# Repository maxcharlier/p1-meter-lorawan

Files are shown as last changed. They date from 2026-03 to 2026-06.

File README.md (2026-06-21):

# Belgian Smart Meter P1 → LoRaWAN

Read your Belgian smart meter (ORES / Fluvius) via the **P1 port** and forward aggregated electrical data over **LoRaWAN** every 15 minutes using a Heltec CubeCell board.

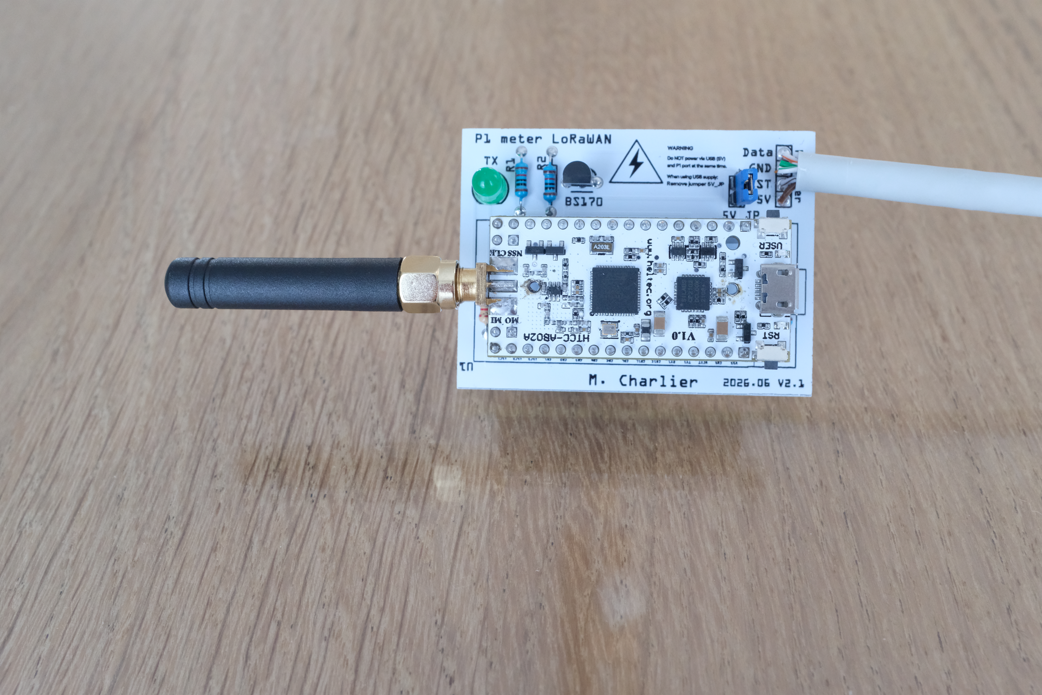
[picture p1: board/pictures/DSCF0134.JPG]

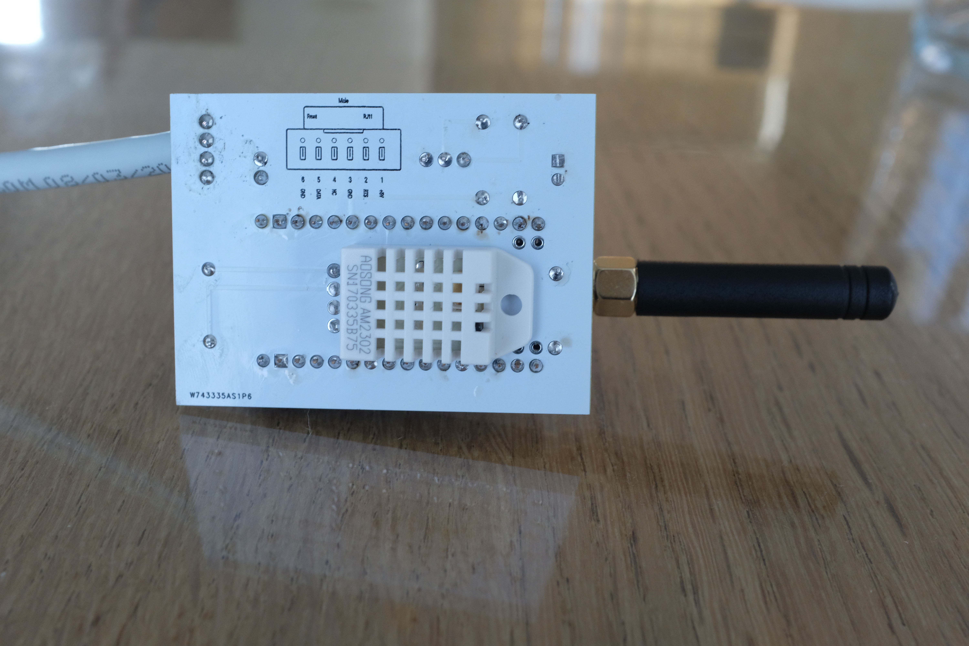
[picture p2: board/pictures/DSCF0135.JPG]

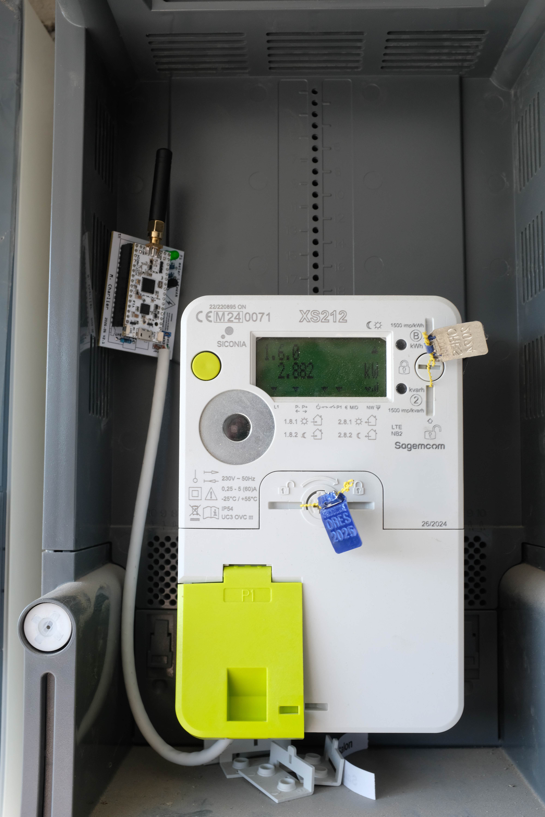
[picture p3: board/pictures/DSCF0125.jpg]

## Quick start

```bash
# 1. Clone the repository
git clone https://github.com/YOUR_USERNAME/p1-meter-lorawan.git
cd p1-meter-lorawan

# 2. Enable the pre-commit hook (blocks accidental credential leaks)
git config core.hooksPath .githooks

# 3. Generate your LoRaWAN credentials from your TTN / Chirpstack device page
python3 credentials.py --deveui AA:BB:CC:DD:EE:FF:00:11 \\
                        --appeui 00:00:00:00:00:00:00:00 \\
                        --appkey AA:BB:CC:DD:EE:FF:00:11:22:33:44:55:66:77:88:99 \\
                        --write-h mono-phase-lorawan/credentials.h

# 4. Install required Arduino libraries (Tools → Manage Libraries):
#    - "DHT sensor library" by Adafruit  (also install its dependency: Adafruit Unified Sensor)

# 5. Open the sketch in Arduino IDE, build and flash
```

> **Credentials:** `credentials.h` is git-ignored. A zeroed template is provided as
> `credentials.h.example` in each sketch folder. The pre-commit hook will block any
> commit that contains non-zero keys in `credentials.h`.

---

## Project steps

| Folder | Purpose |
|---|---|
| [`serial-config-checker/`](serial-config-checker/) | Dump raw P1 serial output to USB — verify wiring and baud rate |
| [`mono-phase-lorawan/`](mono-phase-lorawan/) | Parse OBIS fields, aggregate statistics, transmit over LoRaWAN (single-phase meter) |
| [`three-phase-lorawan/`](three-phase-lorawan/) | Same as above but with L2/L3 voltage and current stats (three-phase meter) |
| [`mono-phase-overvoltage/`](mono-phase-overvoltage/) | mono-phase-lorawan + Synergrid C10/11 over-voltage detection (253 V / 264.5 V) |

Before flashing any sketch, see **[board-setup.md](board-setup.md)** for driver installation, Arduino IDE board support, and upload instructions.

---

## Hardware

### Why the Heltec CubeCell HTCC-AB02A?

The CubeCell HTCC-AB02A was chosen because it exposes **two independent hardware serial (UART) lines**:

- **Serial** (UART0) — connected to the USB bridge, used for debug output and programming.
- **Serial1** (UART1, pins UART_RX2 / UART_TX2) — dedicated to reading the P1 port of the electrical meter.

Having two separate hardware UARTs is essential: the P1 port streams data continuously at 115200 baud 8N1, so it must be handled on a real hardware peripheral — a software serial implementation would lose bytes at that speed or block the LoRaWAN stack.

As an added bonus, the board integrates a **Semtech SX1262 LoRa transceiver and a 868 MHz antenna**, and is supported by the Heltec Arduino SDK with a ready-made LoRaWAN stack.

Board documentation and pinout are available in [`sources/`](sources/).

### Components

| Component | Reference | Notes |
|---|---|---|
| Arduino board | Heltec CubeCell HTCC-AB02A | Two hardware UARTs + integrated LoRa 868 MHz |
| Signal inverter / level shifter | BS170 N-channel MOSFET | Inverts 5 V → 3.3 V (common-drain) |
| Meter connector | RJ11 6P6C | P1 port on Belgian smart meters (pins 1, 2, 3, 5, 6 used) |
| Environmental sensor | DHT22 | Temperature + humidity (all sketches except serial-config-checker) |
| Pull-up resistors | 3 × 10 kΩ (R1, R2) | BS170 inverter biasing (R1 on source/RX2, R2 on gate/Data) |
| DHT pull-up resistor | 1 × 10 kΩ (RPullUpDHT) | DHT22 data line pull-up to VEXT |
| LED current limiter | 1 × 220 Ω (R3) | TX indicator LED |
| TX indicator LED | 5 mm red LED | Driven by GPIO1 via R3 |
| Power jumper | 2-pin header (5V_JP) | Connects P1 +5 V to VIN — **remove when using USB** |
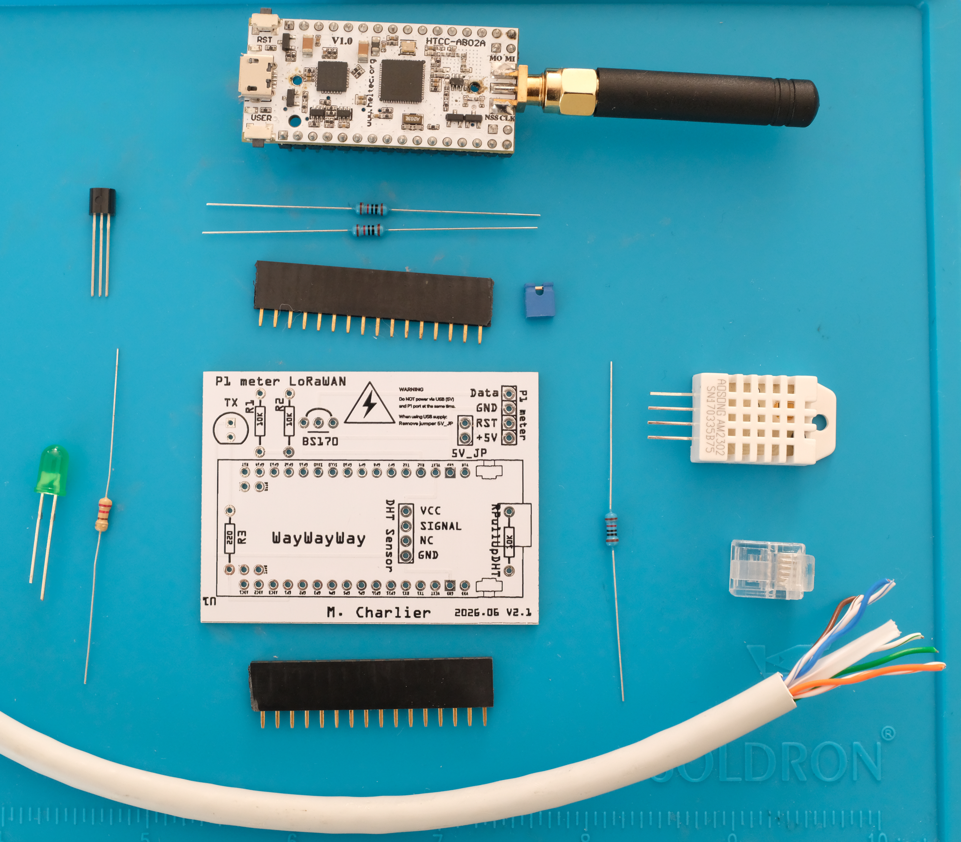
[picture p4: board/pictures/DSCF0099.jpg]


For the PCB, you can print it with gerber files from `board/p1-meter-lorawan-v2.1`. The PCB was created using [Fritzing](https://fritzing.org/) and can be modified in `board/p1-meter-lorawan-v2.1.fzz`
### Wiring — P1 port to CubeCell

> **WARNING — do not connect both power sources at the same time.**
> The CubeCell is powered from the meter's 5 V line (VIN pin).
> If you also plug in a USB cable while the meter is connected, you will feed two power sources into the board simultaneously, which can damage the board or the meter.
> Remove the 5V_JP jumper before connecting USB (for programming or debug).

The P1 port outputs **inverted** 5 V TTL serial (5 V = logic 0, 0 V = logic 1).
The BS170 MOSFET inverts the signal and shifts it to 3.3 V in a single stage using a common-drain configuration:
- **Gate** receives the P1 data signal (with R2 10 kΩ pull-up to GPIO7).
- **Source** outputs the inverted 3.3 V signal to UART_RX2 (with R1 10 kΩ pull-up to GPIO7).
- **Drain** is tied to GND.

GPIO7 is set HIGH to provide 3.3 V through R1 and R2, biasing the inverter. Setting GPIO7 LOW disables reception.

```
Belgian Meter P1 (RJ11 6P6C)     CubeCell HTCC-AB02A
─────────────────────────────────────────────────────
Pin 1  +5V  ─────[5V_JP]────────→  VIN  (powers the board)
Pin 2  RTS  ─────────────────────→  +5V  (Data Request, active HIGH — hardwired to 5 V)
Pin 3  GND  ─────────────────────→  GND
Pin 4  NC
Pin 5  Data ─────────────────────→  BS170 gate (via R2 10 kΩ pull-up to GPIO7)
Pin 6  GND  ─────────────────────→  GND

BS170 inverter (common-drain configuration):
       BS170 gate   ← P1 Data + R2 (10 kΩ pull-up to GPIO7)
       BS170 source → UART_RX2 (Serial1) + R1 (10 kΩ pull-up to GPIO7)
       BS170 drain  → GND

GPIO7 (OUTPUT, set HIGH) provides 3.3 V pull-up bias through R1 and R2,
effectively enabling/disabling the inverter.
```

> **Data Request line**: The P1 spec requires the Data Request line (RJ11 pin 2) to be
> pulled HIGH to enable telegram output. On this PCB, it is hardwired to the +5 V rail,
> so the meter streams continuously whenever power is present.

### DHT22 (mono-phase-lorawan, three-phase-lorawan, mono-phase-overvoltage)

```
DHT22               CubeCell
─────────────────────────────
VCC  ─────────────→  VEXT (switchable 3.3 V)
GND  ─────────────→  GND
DATA ─[10 kΩ]─────→  GPIO9 / SDA1  (pull-up to VEXT)
```

### GPIO pin summary

| GPIO | Direction | Function |
|---|---|---|
| GPIO7  | OUTPUT | BS170 inverter enable (set HIGH to provide 3.3 V pull-up bias via R1 + R2) |
| GPIO9 / SDA1 | INPUT | DHT22 data (10 kΩ pull-up to VEXT) |
| GPIO5  | INPUT  | Floating — used for `randomSeed()` |
| GPIO1  | OUTPUT | TX LED indicator (via R3 220 Ω) |
| USER_KEY | INPUT_PULLDOWN | User button (manual LoRa send) |
| UART_RX2 / UART_TX2 | — | Hardware Serial1, 115200 8N1 (RX2 receives inverted P1 data via BS170) |

---

## P1 port & DSMR/ESMR protocol

Belgian smart meters (Fluvius in Flanders, ORES in Wallonia) expose a **P1 port** that outputs an DSMR 5.0 / ESMR 5.0 telegram every second.

### Telegram structure

```
/FLU5\253770234_A              ← header: slash + manufacturer ID

0-0:1.0.0(240904223307S)       ← OBIS object: timestamp
1-0:1.8.1(000328.928*kWh)      ← OBIS object: consumption T1
...
!E4C7                          ← CRC-16 checksum
```

Each telegram line contains one **OBIS code** followed by its value in parentheses.

### OBIS code format

```
A-B:C.D.E
│ │ │ │ └─ Tariff / sub-index
│ │ │ └─── Quantity (measurement type)
│ │ └───── Value group (channel)
│ └──────── Medium group (0=abstract, 1=electricity, 2=heat, 3=gas, 6=water)
└────────── Energy type
```

### OBIS codes extracted by this project

All sketches (except serial-config-checker) extract these fields:

| OBIS code | Name | Unit | Description |
|---|---|---|---|
| `0-0:1.0.0` | Timestamp | — | Date-time stamp (local time, S=Summer/CEST, W=Winter/CET) |
| `1-0:1.8.1` | Cons-Day-Wh | Wh | Total electricity delivered to client — Tariff 1 (day) |
| `1-0:1.8.2` | Cons-Night-Wh | Wh | Total electricity delivered to client — Tariff 2 (night) |
| `1-0:2.8.1` | Prod-Day-Wh | Wh | Total electricity delivered by client — Tariff 1 (day) |
| `1-0:2.8.2` | Prod-Night-Wh | Wh | Total electricity delivered by client — Tariff 2 (night) |
| `0-0:96.14.0` | Night1-Day2 | — | Active tariff indicator (1=night/T1, 2=day/T2) |
| `1-0:1.7.0` | Cons-W | W | Instantaneous active power import (+P total) |
| `1-0:2.7.0` | Prod-W | W | Instantaneous active power export (-P total) |
| `1-0:32.7.0`  | Inst-L1-dV | dV | Instantaneous voltage L1 (decivolts, divide by 10 for V) |
| `1-0:31.7.0`  | Inst-L1-cA | cA | Instantaneous current L1 (centiamps, divide by 100 for A) |

three-phase-lorawan additionally extracts:

| OBIS code | Name | Unit | Description |
|---|---|---|---|
| `1-0:52.7.0` | Inst-L2-dV | dV | Instantaneous voltage L2 (decivolts) |
| `1-0:72.7.0` | Inst-L3-dV | dV | Instantaneous voltage L3 (decivolts) |
| `1-0:51.7.0` | Inst-L2-cA | cA | Instantaneous current L2 (centiamps) |
| `1-0:71.7.0` | Inst-L3-cA | cA | Instantaneous current L3 (centiamps) |

**Sources:**
- DSMR P1 Companion Standard v5.0.2 — [Netbeheer Nederland](https://www.netbeheernederland.nl/publicatie/dsmr-502-p1-companion-standard)
- Fluvius P1 port specification — [Digitale Meters in Vlaanderen](https://www.fluvius.be/nl/thema/meters-en-meterstanden/digitale-meter)
- ORES S1 port specification (Wallonia)
- IEC 62056-21 / OBIS object identification system

---

## Software architecture

### P1 parser

The telegram parser is adapted from [Maarten Pennings' eMeterP1port project (gen2)](https://github.com/maarten-pennings/eMeterP1port/tree/master/gen2).
It is a character-by-character state machine with CRC-16 validation.

States: `IDLE` → `HEAD` → `BODY` → `CSUM` → `IDLE`

CRC-16 polynomial: `x16 + x15 + x2 + 1` (0xA001 reflected).

### Statistics aggregation

Since LoRaWAN duty-cycle limits transmission to once every 15 minutes, ~900 samples are collected per period. For each measured quantity the code tracks:

- **Minimum** value in the window
- **Maximum** value (critical for voltage spike detection)
- **Mean** (sum / count)
- **Sample count** (data quality)

### LoRaWAN transmission timing

A random delay (15–60 s after a quarter-hour boundary) is added before transmitting to avoid all devices on a network transmitting simultaneously.

### Over-voltage detection (mono-phase-overvoltage only)

Belgian grid protection thresholds per **Synergrid C10/11** and **EN 50549-1** (230 V nominal):

| Stage | Threshold | Trip time | Threshold in decivolts |
|---|---|---|---|
| Stage 1 (U>) | 1.10 × 230 V = **253.0 V** | 1.5 s sustained | 2530 dV |
| Stage 2 (U>>) | 1.15 × 230 V = **264.5 V** | 0.2 s instant | 2645 dV |

When a grid-connected solar inverter detects sustained over-voltage it disconnects and waits ~60 s before reconnecting. This module tracks:

- Total samples above Stage 1 threshold
- Total samples above Stage 2 threshold
- Maximum consecutive samples above Stage 1 (if ≥ 2 consecutive at 1 sample/s → inverter likely tripped)

---

## LoRaWAN payload format (v2)

Each sketch uses the same frame version (v2) and a shared header, with fields added per sketch. The **NB Phases** nibble in byte 0 tells the decoder which format to expect.

### mono-phase-lorawan / mono-phase-overvoltage — 62 bytes (68 with over-voltage)

| Field | Bits | Byte index | Detail |
|---|---|---|---|
| Frame version | 4 | 0 | Value: 2 |
| User button | 1 | 0 | Pressed = 1 |
| NB Phases | 2 | 0 | Value: 1 |
| RESERVED | 1 | 0 | — |
| Timestamp | 32 | 1 | Unix timestamp (UTC) |
| Cons-Day-Wh | 32 | 5 | Cumulative Wh |
| Cons-Night-Wh | 32 | 9 | Cumulative Wh |
| Prod-Day-Wh | 32 | 13 | Cumulative Wh |
| Prod-Night-Wh | 32 | 17 | Cumulative Wh |
| Night1-Day2 | 8 | 21 | Current tariff |
| Nb Samples | 16 | 22 | Sample count in period |
| Cons-W stats | 72 | 24 | Min/Max/Mean (W) |
| Prod-W stats | 72 | 33 | Min/Max/Mean (W) |
| L1-dV stats | 72 | 42 | Min/Max/Mean (decivolts) |
| L1-cA stats | 72 | 51 | Min/Max/Mean (centiamps) |
| Temperature | 8 | 60 | DHT22: `(val / 2) - 40 = °C` |
| Humidity | 8 | 61 | DHT22: 0–100 % |
| L1-over-253V | 16 | 62 | Stage 1 count *(mono-phase-overvoltage only, if > 0)* |
| L1-over-264.5V | 16 | 64 | Stage 2 count *(mono-phase-overvoltage only, if Stage 1 > 0)* |
| L1-max-consec-253 | 16 | 66 | Max streak *(mono-phase-overvoltage only, if Stage 1 > 0)* |

> The 6 over-voltage bytes are only appended when `L1-over-253V > 0`, saving bandwidth in normal operation.

### three-phase-lorawan — 98 bytes

Same header and common fields as above (bytes 0–59), then:

| Field | Bits | Byte index | Detail |
|---|---|---|---|
| Frame version | 4 | 0 | Value: 2 |
| User button | 1 | 0 | Pressed = 1 |
| NB Phases | 2 | 0 | Value: 3 |
| RESERVED | 1 | 0 | — |
| Timestamp | 32 | 1 | Unix timestamp (UTC) |
| Cons-Day-Wh | 32 | 5 | Cumulative Wh |
| Cons-Night-Wh | 32 | 9 | Cumulative Wh |
| Prod-Day-Wh | 32 | 13 | Cumulative Wh |
| Prod-Night-Wh | 32 | 17 | Cumulative Wh |
| Night1-Day2 | 8 | 21 | Current tariff |
| Nb Samples | 16 | 22 | Sample count in period |
| Cons-W stats | 72 | 24 | Min/Max/Mean (W) |
| Prod-W stats | 72 | 33 | Min/Max/Mean (W) |
| L1-dV stats | 72 | 42 | Min/Max/Mean (decivolts) |
| L1-cA stats | 72 | 51 | Min/Max/Mean (centiamps) |
| L2-dV stats | 72 | 60 | Min/Max/Mean (decivolts) |
| L3-dV stats | 72 | 69 | Min/Max/Mean (decivolts) |
| L2-cA stats | 72 | 78 | Min/Max/Mean (centiamps) |
| L3-cA stats | 72 | 87 | Min/Max/Mean (centiamps) |
| Temperature | 8 | 96 | DHT22: `(val / 2) - 40 = °C` |
| Humidity | 8 | 97 | DHT22: 0–100 % |

> 98 bytes requires at least DR3 (SF9/125 kHz) in EU868. DR0–DR2 cannot carry this payload.

Each Min/Max/Mean stat block is 3 × 3 bytes (24-bit little-endian unsigned integers).

---

## Payload decoder

A standalone Python decoder for the LoRaWAN frames is provided in [`decoder/decoder.py`](decoder/decoder.py). It has no dependencies beyond the Python standard library.

### Usage

```bash
# Decode a base64 payload string (as received from a LoRaWAN network server)
python3 decoder/decoder.py <base64_payload>

# Run the built-in examples
python3 decoder/decoder.py
```

### What it decodes

The decoder auto-detects the frame variant from the `NB Phases` bits in the header byte and returns a `DecodedFrame` object with all fields resolved to human-readable units (W, V, A, °C, Wh):

| Variant | Bytes | Auto-detected when |
|---|---|---|
| Mono-phase | 62 | `NB Phases = 1` |
| Mono-phase + overvoltage | 68 | `NB Phases = 1` + 6 extra bytes present |
| Three-phase | 98 | `NB Phases = 3` |

### Using it as a module

```python
from decoder.decoder import decode_base64

frame = decode_base64("Eoih9Gh...")

print(frame.datetime_utc)           # meter timestamp (UTC)
print(frame.index_cons_total_wh)    # total consumption = day + night Wh
print(frame.cons_w.mean)            # mean import power over the 15-min window (W)
print(frame.l1_voltage_v)           # Stats(min=..., max=..., mean=...)  in V
print(frame.overvoltage)            # OvervoltageData or None
```

---

## Sources

Local copies of the key reference documents are in the [`sources/`](sources/) folder.

### P1 port / DSMR protocol

| File | Description |
|---|---|
| `P1 Companion Standard.pdf` | DSMR P1 Companion Standard v5.0.2 — Netbeheer Nederland |
| `p1-companion-standard.pdf` | DSMR P1 Companion Standard (alternate edition) |
| `Slimme_meter_ESMR50.pdf` | ESMR 5.0 — Dutch smart meter requirements |

### Belgian meter operator documentation

| File | Description |
|---|---|
| `fluvius_serial_format.pdf` | Fluvius P1 port serial format (Flanders) |
| `ORES P1 port standard.pdf` | ORES P1 port standard (Wallonia) |
| `ores-s1-port_format.pdf` | ORES S1 port format detail |
| `dmk-demo-v2.1-rtc.pdf` | Digitale Meters in Vlaanderen — full specification |
| `Digitale Meters in Vlaanderen - dmk-demo-v2.1-rtc-p1-p18.pdf` | DMK spec pages 1–18 |
| `Digitale Meters in Vlaanderen - dmk-demo-v2.1-rtc-p19-p57.pdf` | DMK spec pages 19–57 |
| `Digitale Meters in Vlaanderen - dmk-demo-v2.1-rtc-p57-p75.pdf` | DMK spec pages 57–75 |

### Hardware

| File | Description |
|---|---|
| `BS170_FairchildSemiconductor.pdf` | BS170 N-channel MOSFET datasheet (signal inverter) |
| `P1 poort slimme meter uitlezen (hardware).pdf` | P1 hardware wiring guide |
| `AB02A.pdf` | Heltec CubeCell HTCC-AB02A datasheet |
| `HTCC-AB02A_PinoutDiagram.pdf` | CubeCell HTCC-AB02A pinout |
| `HTCC-AB02A_SchematicDiagram.pdf` | CubeCell HTCC-AB02A schematic |
| `CubeCell Series Quick Start — cubecell latest documentation.pdf` | CubeCell getting started guide |

### Articles

| File | Description |
|---|---|
| `Read data from the Belgian digital meter through the P1 port Jensd's I_O buffer.pdf` | Jensd blog — reading the Belgian P1 meter (basis for this project) |

## Resources

- [Maarten Pennings — eMeterP1port (parser basis)](https://github.com/maarten-pennings/eMeterP1port/tree/master/gen2)
- [DSMR P1 Companion Standard v5.0.2](https://www.netbeheernederland.nl/publicatie/dsmr-502-p1-companion-standard)
- [Jensd — Read data from the Belgian digital meter through the P1 port](https://jensd.be/1183/linux/read-data-from-the-belgian-digital-meter-through-the-p1-port)
- [domoticx.com — P1 poort slimme meter uitlezen (hardware)](http://domoticx.com/p1-poort-slimme-meter-uitlezen-hardware/)
- [Heltec CubeCell HTCC-AB02A documentation](https://heltec.org/project/htcc-ab02a/)
- [Synergrid C10/11 — Grid connection regulations Belgium](https://www.synergrid.be/)
- [EN 50549-1 — Requirements for generating plants to be connected in parallel with distribution networks](https://www.en-standard.eu/)

---

## License

MIT — see [LICENSE](LICENSE).

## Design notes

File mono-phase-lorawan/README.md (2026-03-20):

# Mono-phase — LoRaWAN transmission

Parse the P1 telegram, aggregate per-second measurements over a 15-minute window, and transmit a compact LoRaWAN frame at each quarter-hour boundary.

Features:
- OBIS field parsing with CRC-16 validation
- Min / Max / Mean statistics for power, voltage, and current
- DHT22 temperature + humidity (2 bytes in payload)
- Random transmission delay (15–60 s after quarter boundary) to reduce network congestion
- User button triggers an immediate manual transmission

## Setup

> **WARNING — do not connect both power sources at the same time.**
> The board is powered from the meter's 5 V line (VIN). If you also plug in USB while the meter is connected, two power sources will be active simultaneously and can damage the board or the meter.
> Disconnect the RJ11 cable before connecting USB for programming, then reconnect it.

1. Copy `credentials.h` from `credentials.h.example` (or use the provided zeroed template) and fill in your LoRaWAN OTAA keys.
2. Set `DEBUG 1` in the sketch to enable serial debug output during development, then set it back to `0` for production.
3. Upload to the CubeCell HTCC-AB02A board.

## LoRaWAN payload format (v2)

Frame size: **62 bytes**.

| Field | Bits | Byte index | Detail |
|---|---|---|---|
| Frame version | 4 | 0 | Value: 2 |
| User button | 1 | 0 | Pressed = 1 |
| NB Phases | 2 | 0 | Value: 1 |
| RESERVED | 1 | 0 | — |
| Timestamp | 32 | 1 | Unix timestamp (UTC) |
| Cons-Day-Wh | 32 | 5 | Cumulative Wh |
| Cons-Night-Wh | 32 | 9 | Cumulative Wh |
| Prod-Day-Wh | 32 | 13 | Cumulative Wh |
| Prod-Night-Wh | 32 | 17 | Cumulative Wh |
| Night1-Day2 | 8 | 21 | Current tariff |
| Nb Samples | 16 | 22 | Sample count in period |
| Cons-W stats | 72 | 24 | Min/Max/Mean (W) |
| Prod-W stats | 72 | 33 | Min/Max/Mean (W) |
| L1-dV stats | 72 | 42 | Min/Max/Mean (decivolts) |
| L1-cA stats | 72 | 51 | Min/Max/Mean (centiamps) |
| Temperature | 8 | 60 | `(val / 2) - 40 = °C` |
| Humidity | 8 | 61 | 0–100 % |

Each Min/Max/Mean block: 3 × 3 bytes, 24-bit little-endian unsigned integers.

## Next step

To add Synergrid C10/11 over-voltage detection (253 V / 264.5 V thresholds) → [mono-phase-overvoltage](../mono-phase-overvoltage/).

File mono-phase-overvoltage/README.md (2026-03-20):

# Mono-phase — Over-voltage detection

Everything from [mono-phase-lorawan](../mono-phase-lorawan/), plus Synergrid C10/11 / EN 50549-1 compliant over-voltage monitoring.

This step is designed for households with solar installations where grid over-voltage can cause the inverter to disconnect.

## Over-voltage thresholds (Belgium, 230 V nominal)

| Stage | Threshold | Trip time | Use |
|---|---|---|-----|
| Stage 1 (U>) | **253.0 V** (1.10 × 230 V) | 1.5 s sustained | Sustained over-voltage, inverter trips after ~1.5 s |
| Stage 2 (U>>) | **264.5 V** (1.15 × 230 V) | 0.2 s instant | Extreme spike, instant trip |

Per sample (1 sample/s), if `max_consecutive_over_stage1 >= 2` the inverter very likely tripped.

## What is tracked per 15-minute window

- `L1-over-253V` — total samples where voltage ≥ 253.0 V
- `L1-over-264.5V` — total samples where voltage ≥ 264.5 V
- `L1-max-consec-253` — longest uninterrupted streak above 253.0 V

## LoRaWAN payload format (v2)

Frame size: **62 bytes** normally, **68 bytes** when over-voltage occurred.

| Field | Bits | Byte index | Detail |
|---|---|---|---|
| Frame version | 4 | 0 | Value: 2 |
| User button | 1 | 0 | Pressed = 1 |
| NB Phases | 2 | 0 | Value: 1 |
| RESERVED | 1 | 0 | — |
| Timestamp | 32 | 1 | Unix timestamp (UTC) |
| Cons-Day-Wh | 32 | 5 | Cumulative Wh |
| Cons-Night-Wh | 32 | 9 | Cumulative Wh |
| Prod-Day-Wh | 32 | 13 | Cumulative Wh |
| Prod-Night-Wh | 32 | 17 | Cumulative Wh |
| Night1-Day2 | 8 | 21 | Current tariff |
| Nb Samples | 16 | 22 | Sample count in period |
| Cons-W stats | 72 | 24 | Min/Max/Mean (W) |
| Prod-W stats | 72 | 33 | Min/Max/Mean (W) |
| L1-dV stats | 72 | 42 | Min/Max/Mean (decivolts) |
| L1-cA stats | 72 | 51 | Min/Max/Mean (centiamps) |
| Temperature | 8 | 60 | `(val / 2) - 40 = °C` |
| Humidity | 8 | 61 | 0–100 % |
| L1-over-253V | 16 | 62 | Stage 1 count *(only if > 0)* |
| L1-over-264.5V | 16 | 64 | Stage 2 count *(only if Stage 1 > 0)* |
| L1-max-consec-253 | 16 | 66 | Max consecutive streak *(only if Stage 1 > 0)* |

> The 6 over-voltage bytes are only appended when `L1-over-253V > 0`, saving bandwidth in normal operation.

## Setup

> **WARNING — do not connect both power sources at the same time.**
> The board is powered from the meter's 5 V line (VIN). If you also plug in USB while the meter is connected, two power sources will be active simultaneously and can damage the board or the meter.
> Disconnect the RJ11 cable before connecting USB for programming, then reconnect it.

1. Copy `credentials.h` from the provided zeroed template and fill in your LoRaWAN OTAA keys.
2. Set `DEBUG 1` during testing.
3. Upload to the CubeCell HTCC-AB02A board.

## References

- Synergrid C10/11: [synergrid.be](https://www.synergrid.be/)
- EN 50549-1: Requirements for generating plants connected in parallel with distribution networks

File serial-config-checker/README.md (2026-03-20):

# Serial Config Checker

Bridge the meter's P1 serial port to USB so you can inspect the raw P1 telegram in a serial monitor.

Use this step to:
- Verify that your wiring is correct
- Confirm the baud rate (115200 8N1 for Belgian ESMR 5.0 meters)
- See which OBIS fields your specific meter outputs
- Capture sample telegrams for offline testing

## How to use

> **WARNING — do not connect both power sources at the same time.**
> The board is powered from the meter's 5 V line (VIN). If you also plug in USB while the meter is connected, two power sources will be active simultaneously and can damage the board or the meter.
> Disconnect the RJ11 cable before connecting USB, and reconnect it afterwards.

1. Upload `serial-config-checker.ino` to the CubeCell board (USB only, RJ11 disconnected).
2. Disconnect USB, connect the RJ11 cable to the meter.
3. The board is now powered by the meter — open a serial monitor at **115200 baud** via USB if needed, but do not connect USB power at the same time.
3. One telegram per second should appear, starting with `/` and ending with `!XXXX`.

## Expected output

```
/FLU5\253770234_A

0-0:96.1.4(50217)
0-0:1.0.0(240904223307S)
1-0:1.8.1(000328.928*kWh)
1-0:1.8.2(000312.703*kWh)
1-0:2.8.1(000000.035*kWh)
1-0:2.8.2(000000.000*kWh)
0-0:96.14.0(0002)
1-0:1.7.0(00.247*kW)
1-0:2.7.0(00.000*kW)
1-0:32.7.0(238.7*V)
1-0:31.7.0(001.21*A)
!E4C7
```

## Notes

- The sketch bridges `Serial1` (meter) → `Serial` (USB) in the `loop()`.
- `GPIO10` powers the BS170 inverter circuit.
- `GPIO7` (OD_HI) holds the Data Request line HIGH to enable continuous output.
- The `readOneMeterMessage()` helper function is present but not called from `loop()` — it is a starting point for message-based reading.

## Next step

Once you can see clean telegrams → proceed to [mono-phase-lorawan](../mono-phase-lorawan/) (single-phase meter) or [three-phase-lorawan](../three-phase-lorawan/) (three-phase meter).

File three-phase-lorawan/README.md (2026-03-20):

# Three-phase — LoRaWAN transmission

Parse the P1 telegram from a **three-phase smart meter**, aggregate per-second measurements over a 15-minute window, and transmit a compact LoRaWAN frame at each quarter-hour boundary.

Extends [mono-phase-lorawan](../mono-phase-lorawan/) with per-phase voltage and current statistics for L2 and L3.

Features:
- OBIS field parsing with CRC-16 validation
- Min / Max / Mean statistics for power, voltage, and current on all three phases (L1, L2, L3)
- DHT22 temperature + humidity (2 bytes in payload)
- Random transmission delay (15–60 s after quarter boundary) to reduce network congestion
- User button triggers an immediate manual transmission

## Setup

> **WARNING — do not connect both power sources at the same time.**
> The board is powered from the meter's 5 V line (VIN). If you also plug in USB while the meter is connected, two power sources will be active simultaneously and can damage the board or the meter.
> Disconnect the RJ11 cable before connecting USB for programming, then reconnect it.

1. Copy `credentials.h` from `credentials.h.example` (or use the provided zeroed template) and fill in your LoRaWAN OTAA keys.
2. Set `DEBUG 1` in the sketch to enable serial debug output during development, then set it back to `0` for production.
3. Upload to the CubeCell HTCC-AB02A board.

> **Note on LoRaWAN payload size:** The frame is 98 bytes. In EU868, this requires at least DR3 (SF9/125 kHz, max 115 bytes). DR0–DR2 cannot carry this payload — ensure your network server and device use ADR or a fixed data rate of DR3 or higher.

## Additional OBIS fields (vs mono-phase)

| OBIS code | Name | Unit | Description |
|---|---|---|---|
| `1-0:52.7.0` | Inst-L2-dV  | dV | Instantaneous voltage L2 (decivolts) |
| `1-0:72.7.0` | Inst-L3-dV  | dV | Instantaneous voltage L3 (decivolts) |
| `1-0:51.7.0` | Inst-L2-cA  | cA | Instantaneous current L2 (centiamps) |
| `1-0:71.7.0` | Inst-L3-cA  | cA | Instantaneous current L3 (centiamps) |

## LoRaWAN payload format (v2, three-phase)

Frame size: **98 bytes**.

| Field | Bits | Byte index | Detail |
|---|---|---|---|
| Frame version | 4 | 0 | Value: 2 |
| User button | 1 | 0 | Pressed = 1 |
| NB Phases | 2 | 0 | Value: 3 |
| RESERVED | 1 | 0 | — |
| Timestamp | 32 | 1 | Unix timestamp (UTC) |
| Cons-Day-Wh | 32 | 5 | Cumulative Wh |
| Cons-Night-Wh | 32 | 9 | Cumulative Wh |
| Prod-Day-Wh | 32 | 13 | Cumulative Wh |
| Prod-Night-Wh | 32 | 17 | Cumulative Wh |
| Night1-Day2 | 8 | 21 | Current tariff |
| Nb Samples | 16 | 22 | Sample count in period |
| Cons-W stats | 72 | 24 | Min/Max/Mean (W) |
| Prod-W stats | 72 | 33 | Min/Max/Mean (W) |
| L1-dV stats | 72 | 42 | Min/Max/Mean (decivolts) |
| L1-cA stats | 72 | 51 | Min/Max/Mean (centiamps) |
| L2-dV stats | 72 | 60 | Min/Max/Mean (decivolts) |
| L3-dV stats | 72 | 69 | Min/Max/Mean (decivolts) |
| L2-cA stats | 72 | 78 | Min/Max/Mean (centiamps) |
| L3-cA stats | 72 | 87 | Min/Max/Mean (centiamps) |
| Temperature | 8 | 96 | `(val / 2) - 40 = °C` |
| Humidity | 8 | 97 | 0–100 % |

Each Min/Max/Mean block: 3 × 3 bytes, 24-bit little-endian unsigned integers.

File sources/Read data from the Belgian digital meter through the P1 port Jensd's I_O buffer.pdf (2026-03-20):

# Read data from the Belgian digital meter through the P1 port

Posted on 04/02/2021 (https://jensd.be/1183/linux/read-data-from-the-belgian-digital-meter-through-the-p1-port)

Like some other Belgians, unfortunately, my analog electricity meter was replaced by a digital one since a few months. Initially, I was quite happy with the change as it allows a much easier look into your consumption and solar panel injection to the net. But exactly that last turned out to be a bummer as the government decided to not keep their word regarding reversing consumption with solar panel injection. Nevertheless, I have the thing so I might as well take advantage of it. This post describes how to connect to and use the data from the P1 port on a digital electricity meter in Belgium.

### YouTube Video

If you are interested, I also created a YouTube video from this blogpost. If you prefer classic text, you can just follow the rest of this article:

## Introduction

Digital electricity meters are used in a variety of countries. While exploring this, I noticed that each country/ region and even device model works in a slightly different way and standard (more about this further in the post). As this post mainly would be interesting for people living in Belgium, for the first time, I decided to also create a Dutch version. You can find this one over here: https://jensd.be/1205/linux/data-lezen-van-de-

# Jensd's I/O buffer (https://jensd.be/)

random technotes…

belgische-digitale-meter-met-de-p1-poort (https://jensd.be/1205/linux/data-lezen-van-de-belgische-digitale-meter-met-de-p1-poort)

The electricity meter is communicating back it’s reading, additional data and natural gas meter’s readings back to the distributor, using cellular, on regular times. This allows you to check that data on the site of the distributor itself:

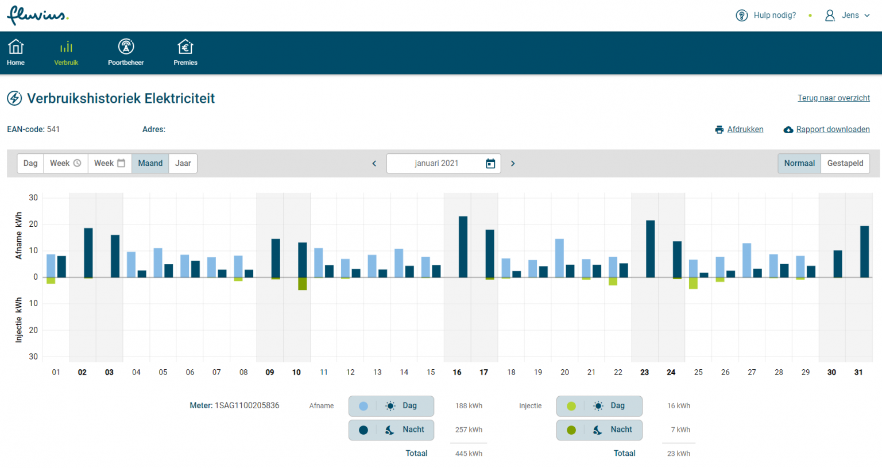
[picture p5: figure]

So if your goal is just to see the consumption in a nice graph there is no need to make use of the data coming from the P1 port. If you want to do something with the data on the other hand, like triggering automation or have the ability to use the near real-time information, you are at the right place.

## The digital meter

In Belgium, distributor Fluvius has started distribution and installation of the digital meters. They are currently using only three types of digital meters for consumers. One for single phase installations, another for three-phase and a natural gas meter that uses the digital electricity meter to send it’s data as well to the distributor:

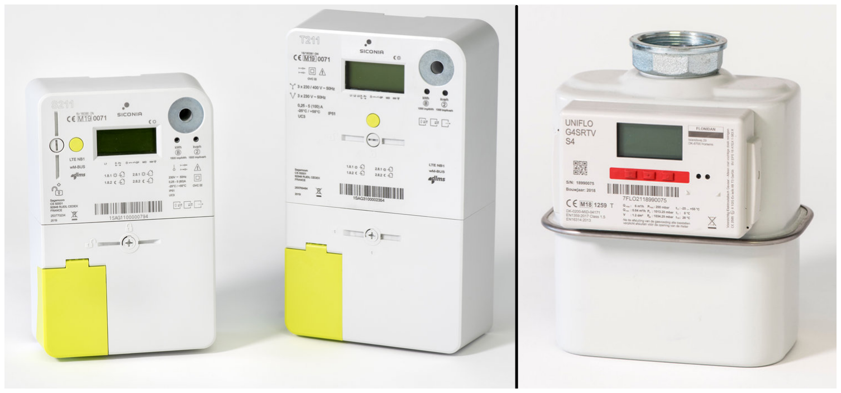
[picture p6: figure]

- Sagecom S211: Single phase
- Sagecom T211-D : Three-phase
- Flonidan – G4SRTV: Natural gas

## The P1 and S1 ports

The electricity meters mentioned above, are having two serial ports on the front of the device, behind the yellow cover. Both these ports can be used to read data from. S1 is sending raw data around 2600-4000 times/second. P1 on the other hand is a bit calmer and provides information around once/second in a more formatted form.

The P1 port, which I will use through the rest of the article, is the most interesting for most users and automation integration.

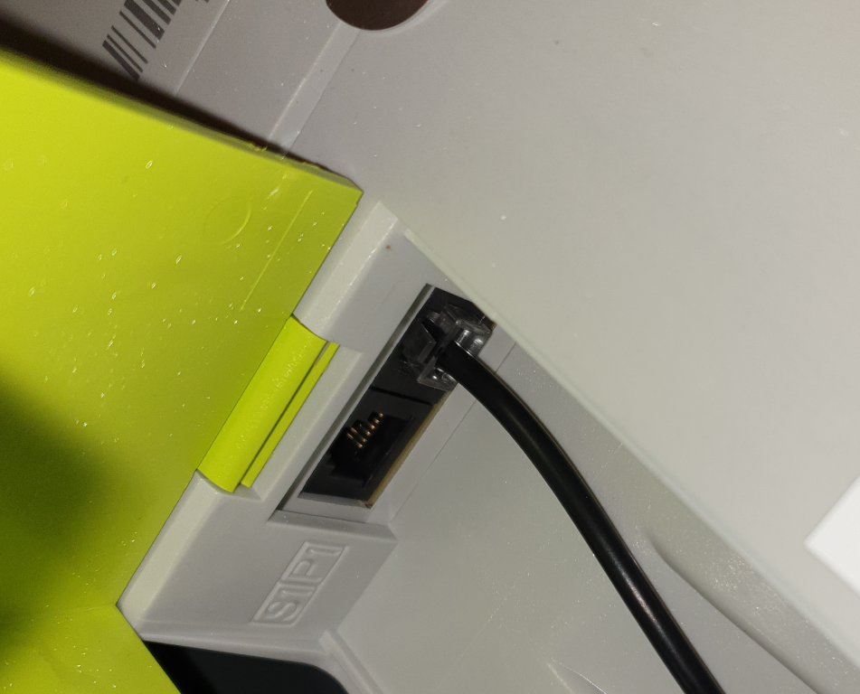
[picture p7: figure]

### Physical port

Both the P1 and S1 ports are following the serial RS422 standard and are using a RJ12 connector. (RJ11 works as well with the correct pinout). Important to know is that these ports are disabled by default. Fortunately, they can easily be enabled using the Fluvius webinterface through https://mijn.fluvius.be/poortbeheer/.

To connect to the ports, you can create a cable yourself with the following pinout:

PIN | SIGNAL | DESCRIPTION
1 | +5V | Power supply for reading equipment (optional)
2 | RTS | Input
3 | GND | Data ground
4 | – | –

PIN | SIGNAL | DESCRIPTION
6 | RX | Output
6 | Power GND | Power supply for reading equipment (optional)

Another option, if you can’t make a cable or are lazy as me, is to buy one of the readily available cables with a serial to usb convertor integrated, like the following:

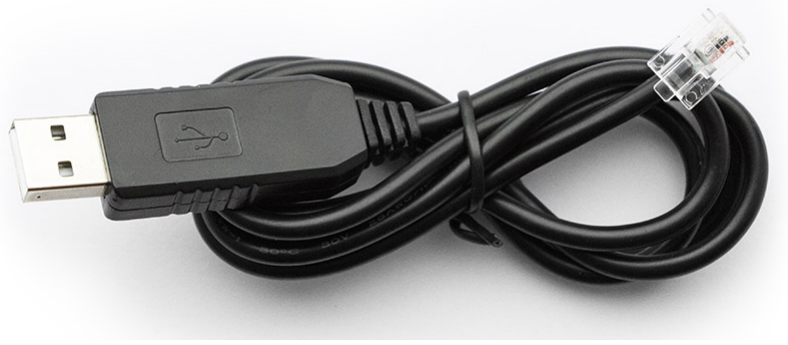
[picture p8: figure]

### Data format

The data format of the P1 port, as well as the above discussed physical format, is using the DSMR 5.0.2 P1 standard. DSMR stands for Dutch Smart Meter Requirements. And as the name suggests, this was developed and is maintained by our northern neighbors. Unfortunately, while looking up information and seeing the various scripts that are available, I noticed that each model of meter seems to use the standard in slightly different ways. So most of what I will discuss in this post applies to other countries that use DSMR but it might needs some tweaks here and there.

You can find all details of the standard over here: https://www.netbeheernederland.nl/_upload/Files/Slimme_meter_15_a727fce1f1.pdf (https://www.netbeheernederland.nl/_upload/Files/Slimme_meter_15_a727fce1f1.pdf)

To not go to deep but still make things understandable, I’ll try to go through the things you need to know from this in order to start using the data.

The whole message (called telegram or COSEM object), coming from the P1 port in DSMR like the following:

And the data itself, inside the telegram, looks like the following:

This gives us the following info:

- Each block of info (telegram) starts with a /
- After the start, there is a fixed, model specific identification, followed with a fixed device-unique

identification
- The data lines start with an OBIS code, including identification from which meter (electricity or natural gas) the data comes and which type of info is next
- The values are inside parentheses and if a unit is preset, it’s separated by a *
- The block of info (telegram) ends with a !
- The CRC field contains a CRC16 calculated value of the rest of the block

### In practice: reading and interpreting the data

So far I’ve only covered things from a theoretical angle. Next, let me explain how you can read the data and parse it to do something useful with it.

For this, I’ll start with a minimal install of Debian but another Linux distribution, like Ubuntu, CentOS, or even Windows/OS X should work in the same way.

First, I’ll install pyserial and crcmod using the package manager as I will use Python to parse the data coming from the P1 port.

jensd@deb10:~$ sudo apt install python3-serial python3-crcmod python3-tabulate
Reading package lists… Done
Building dependency tree
Setting up python3-serial (3.4-4) ...

Next, just to get started, we can try and read out the serial port. In my case, as I mentioned above, I use the P1 cable with integrated serial to USB convertor so my serial port is /dev/ttyUSB0. Port settings for P1 are 115200 baud, 8N1, Xon/Xoff.

In order for a non-root user to access the serial port, we need to set the right permissions:

jensd@deb10:~$ sudo chmod o+rw /dev/ttyUSB0

And to, finally, test the data coming in:

jensd@deb10:~$ python3 -m serial.tools.miniterm /dev/ttyUSB0 115200 --xonxoff
--- Miniterm on /dev/ttyUSB0 115200,8,N,1 ---
--- Quit: Ctrl+] | Menu: Ctrl+T | Help: Ctrl+T followed by Ctrl+H ---
925*m3)
!CE4E
/FLU5\253xxxxxx_A

0-0:96.1.4(xxxxx)
0-0:96.1.1(xxxxxxxxxxxxxxxxxxxxxxxxxxxx) 0-0:1.0.0(210204163628W)
1-0:1.8.1(000439.094kWh)
1-0:1.8.2(000435.292kWh)
1-0:2.8.1(000035.805kWh)
1-0:2.8.2(000012.156kWh)
0-0:96.14.0(0001)
1-0:1.7.0(00.233kW)

1-0:2.7.0(00.000kW)
1-0:21.7.0(00.233kW)
1-0:22.7.0(00.000kW)
1-0:32.7.0(236.2V)
1-0:31.7.0(002.04A)
0-0:96.3.10(1)
0-0:17.0.0(999.9kW)
1-0:31.4.0(999A)
0-0:96.13.0()
0-1:24.1.0(003)
0-1:96.1.1(xxxxxxxxxxxxxxxxxxxxxxxxxxxx) 0-1:24.4.0(1)
0-1:24.2.3(210204163500W)(00343.925*m3) !1374
/FLU5\253xxxxxx_A

0-0:96.1.4(xxxxx)
0-0:96.1.1(xxxxxxxxxxxxxxxxxxxxxxxxxxxx) 0-0:1.0.0(210204163629W)
1-0:1.8.1(000439.094kWh)
1-0:1.8.2(000435.292kWh)
1-0:2.8.1(000035.805kWh)
1-0:2.8.2(000012.156kWh)
0-0:96.14.0(0001)
1-0:1.7.0(00.228kW)
1-0:2.7.0(00.000kW)
1-0:21.7.0(00.228kW)
1-0:22.7.0(00.000kW)
1-0:32.7.0(236.3V)
1-0:31.7.0(002.01A)
0-0:96.3.10(1)
0-0:17.0.0(999.9kW)
1-0:31.4.0(999A)
0-0:96.13.0()
0-1:24.1.0(003)
0-1:96.1.1(xxxxxxxxxxxxxxxxxxxxxxxxxxxx) 0-1:24.4.0(1)
0-1:24.2.3(210204163500W)(00343.925*m3) !4BE6

--- exit ---

As you can see, this matches with the message format for DSMR that I described above. Looking in the documentation, we can find the meaning of these values. This is not always easy as the codes are not an exact match and can contain channel or meter ID. For the examples above, the following applies. I added some other useful ones as well for completeness. More info, specifically for the Belgian meters can be found here as well: https://www.fluvius.be/sites/fluvius/files/2020-02/technische-info-displays-digitale-elektriciteitsmeter.pdf (https://www.fluvius.be/sites/fluvius/files/2020-02/technische-info-displays-digitale-elektriciteitsmeter.pdf)

OBIS CODE | MEANING
0-0:96.1.4 | ID
0-0:96.1.1 | Serial number of electricity meter (in ASCII hex)

OBIS CODE | MEANING
0-0:1.0.0 | Timestamp of the telegram
1-0:1.8.1 | Rate 1 (day) – total consumption
1-0:1.8.2 | Rate 2 (night) – total consumption
1-0:2.8.1 | Rate 1 (day) – total production
1-0:2.8.2 | Rate 2 (night) – total production
0-0:96.14.0 | Current rate (1=day,2=night)
1-0:1.7.0 | All phases consumption
1-0:2.7.0 | All phases production
1-0:21.7.0 | L1 consumption
1-0:41.7.0 | L2 consumption
1-0:61.7.0 | L3 consumption
1-0:22.7.0 | L1 production
1-0:42.7.0 | L2 production
1-0:62.7.0 | L3 production
1-0:32.7.0 | L1 voltage
1-0:52.7.0 | L2 voltage
1-0:72.7.0 | L3 voltage
1-0:31.7.0 | L1 current
1-0:51.7.0 | L2 current
1-0:71.7.0 | L3 current
0-0:96.3.10 | Switch position electricity
0-0:17.0.0 | Max. allowed power/phase
1-0:31.4.0 | Max. allowed current/plase
0-0:96.13.0 | Message
0-1:24.1.0 | Other devices on bus
0-1:96.1.1 | Serial number of natural gas meter (in ASCII hex)
0-1:24.4.0 | Switch position natural gas
0-1:24.2.3 | Reading from natural gas meter (timestamp) (value)

## Ptyhon script

Running this through a Python script to parse the data, results in the following:

### 40 THOUGHTS ON “READ DATA FROM THE BELGIAN DIGITAL METER THROUGH THE P1 PORT”

Pingback: Data lezen van de Belgische digitale meter met de P1 poort | Jensd's I/O
buffer (https://jensd.be/1205/linux/data-lezen-van-de-belgische-digitale-meter-met-de-p1-poort)

jensd@deb10:~$ python3 test.py

Description | Value | Unit
Meter serial electricity | XXXXXXXXXXXXXX
Timestamp | 210204172711.0
Rate 1 (day) - total consumption | 439.33 | kWh
Rate 2 (night) - total consumption | 435.292 | kWh
Rate 1 (day) - total production | 35.805 | kWh
Rate 2 (night) - total production | 12.156 | kWh
Current rate (1=day,2=night) | 1.0
All phases consumption | 0.329 | kW
All phases production | 0.0 | kW
L1 consumption | 0.329 | kW
L1 production | 0.0 | kW
L1 voltage | 238.3 | V
L1 current | 2.18 | A
Switch electricity | 1.0
Meter serial gas | XXXXXXXXXXXXXX
Switch gas | 1.0
Gas consumption | 343.925 | m3

In case you are interested in this script, I uploaded it to GitHub: https://github.com/jensdepuydt/belgian_digitalmeter_p1 (https://github.com/jensdepuydt/belgian_digitalmeter_p1)

The script definitely needs more attention but I guess it can serve well as a source for someone that wants to set up his/her small project by using the data coming from the P1 port.

Let me know your thoughts in the comment section!

This entry was posted in Linux, (https://jensd.be/category/linux) Python, (https://jensd.be/category/scripting/python) Scripting (https://jensd.be/category/scripting) by jensd. (https://jensd.be/author/jensd) Bookmark the permalink [https://jensd.be/1183/linux/read-data-from-the-belgian-digital-meter-through-the-p1-port] (https://jensd.be/1183/linux/read-data-from-the-belgian-digital-meter-through-the-p1-port) .

Robin
on 02/03/2021 at 15:31 (https://jensd.be/1183/linux/read-data-from-the-belgian-digital-meter-through-the-p1-port) said:

Hi Jens,

I followed your tutorial but i’m not receiving any readable data. I only get question marks.

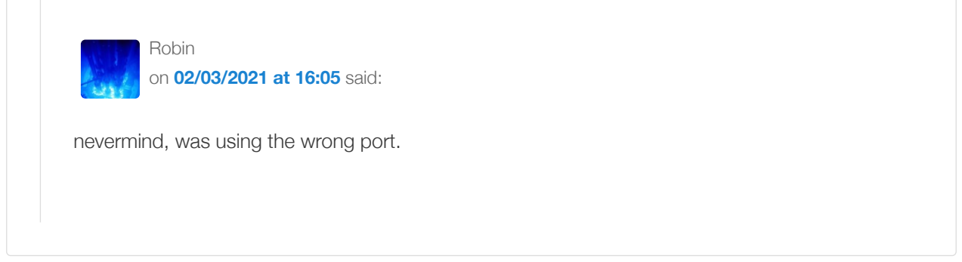
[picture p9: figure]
Robin on 02/03/2021 at 16:05 said:; nevermind, was using the wrong port.
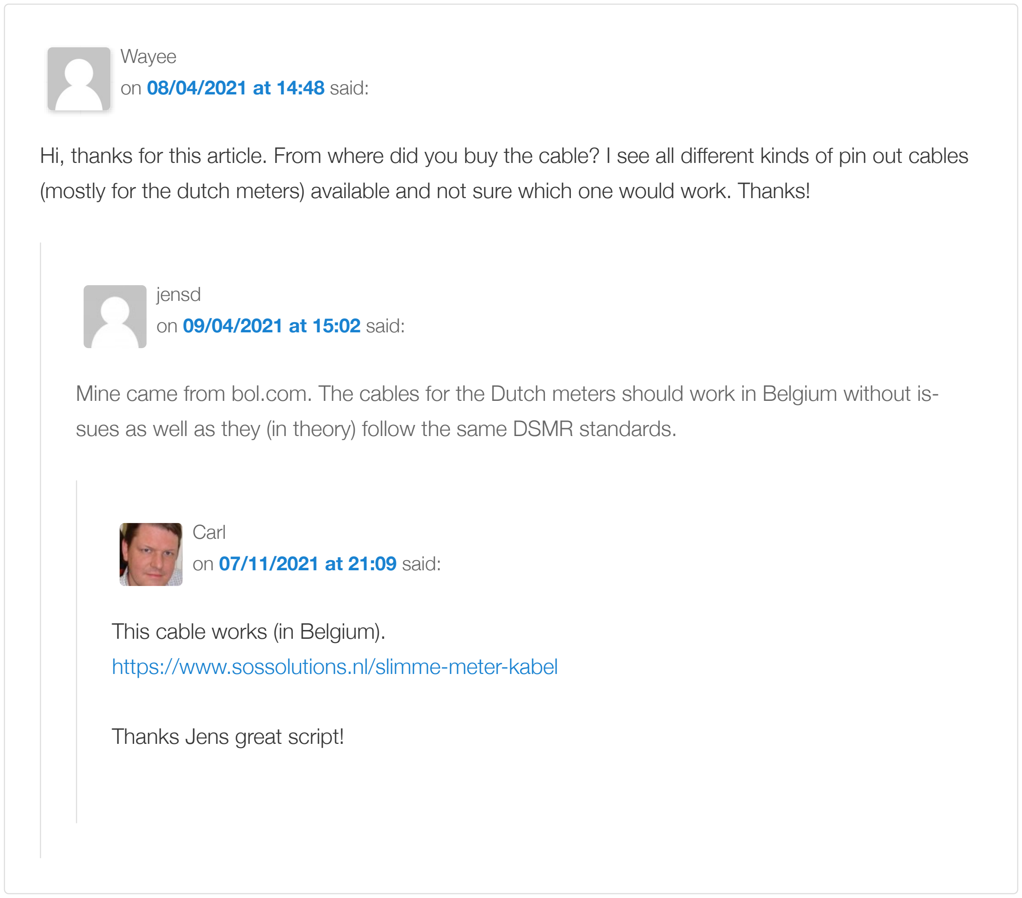
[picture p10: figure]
Wayee on 08/04/2021 at 14:48 said:; jensd on 09/04/2021 at 15:02 said:; Carl on 07/11/2021 at 21:09 said:; This cable works (in Belgium). https://www.sossolutions.nl/slimme-meter-kabel; Thanks Jens great script!

Hi, thanks for this article. From where did you buy the cable? I see all different kinds of pin out cables (mostly for the dutch meters) available and not sure which one would work. Thanks!

Mine came from bol.com. The cables for the Dutch meters should work in Belgium without is‐ sues as well as they (in theory) follow the same DSMR standards.

Albert
on 20/05/2021 at 09:57 (https://jensd.be/1183/linux/read-data-from-the-belgian-digital-meter-through-the-p1-port) said:

Hi Jens,

Thanks for the work you have done, tried your python script but failed with errors. python read_p1.py
File “read_p1.py”, line 62
print(f”Given checksum: {givencrc}, Calculated checksum: {calccrc}”)
^
SyntaxError: invalid syntax

using raspberry pi os with python Python 2.7.16

Hope you know what is failing, Thanks in Advance.

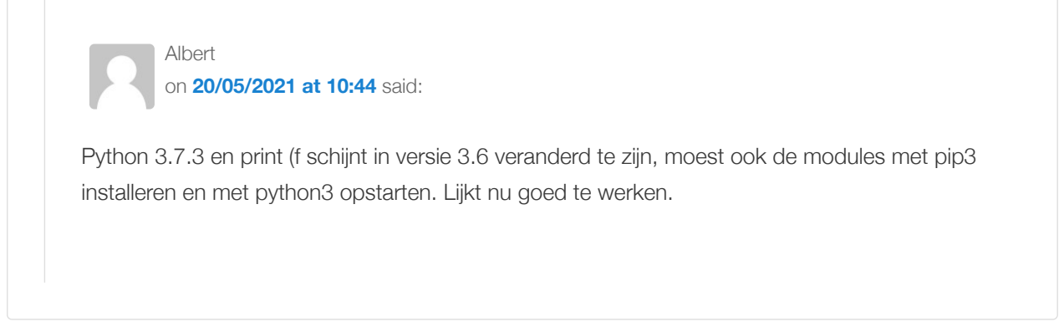
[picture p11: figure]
Albert on 20/05/2021 at 10:44 said:

Python 3.7.3 en print (f schijnt in versie 3.6 veranderd te zijn, moest ook de modules met pip3 installeren en met python3 opstarten. Lijkt nu goed te werken.

Benjamin Schiller
on 14/06/2021 at 16:03 (https://jensd.be/1183/linux/read-data-from-the-belgian-digital-meter-through-the-p1-port) said:

Hi Jens! Thanks a lot for this article. It was super easy with your guideline to get the data out of the smart meter and saved me a lot of time. Also a big thanks for having it done in English.

Unfortunately my IT knowledge is limited I’ve nothing to contribute except that I can say that Sibelga (grid operator in Brussels?) has the P1 open/active by default (understood it’s different to Fluvius).

jensd
on 17/06/2021 at 15:27 (https://jensd.be/1183/linux/read-data-from-the-belgian-digital-meter-through-the-p1-port) said:

Hi Benjamin, that’s useful information. Thanks for sharing here.

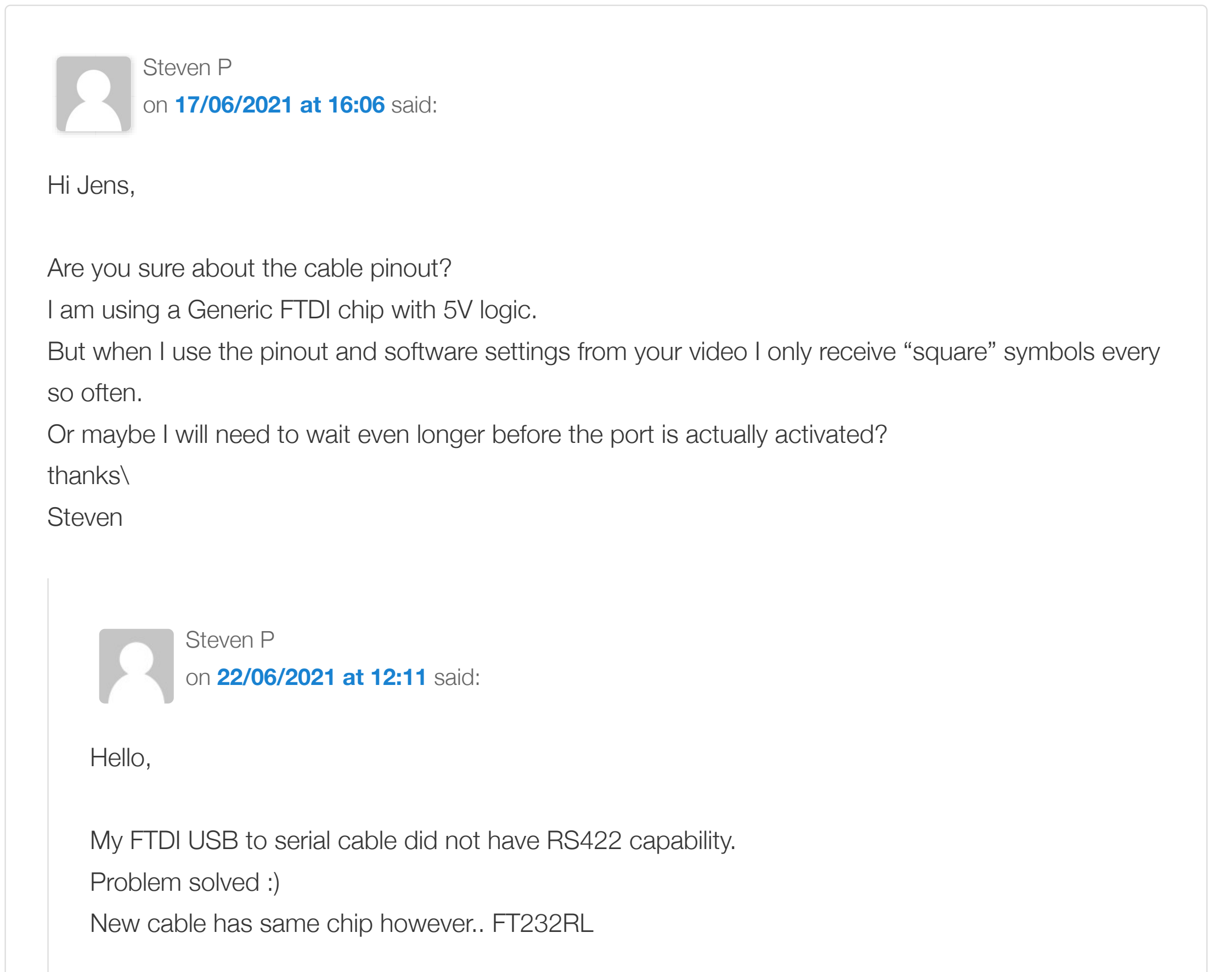
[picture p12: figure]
Steven P on 17/06/2021 at 16:06 said:; Hi Jens,; Are you sure about the cable pinout?; so often.; thanks\ Steven; Steven P on 22/06/2021 at 12:11 said:; Hello,; Problem solved :)

I am using a Generic FTDI chip with 5V logic.
But when I use the pinout and software settings from your video I only receive “square” symbols every

Or maybe I will need to wait even longer before the port is actually activated?

My FTDI USB to serial cable did not have RS422 capability.

New cable has same chip however.. FT232RL

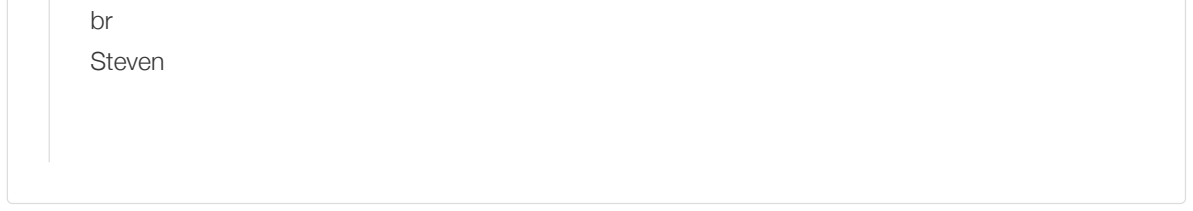
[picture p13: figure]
br Steven

Jean-Pierre Kuypers
on 23/07/2021 at 12:08 (https://jensd.be/1183/linux/read-data-from-the-belgian-digital-meter-through-the-p1-port) said:

Hello,
Having ordered a smart meter from Ores, I now discover your site.
Very interesting !

The installation of the new meter is scheduled for Tuesday, September 14, and I am preparing to collect and process the data provided on port P1.

I would like to point out a typo in the “Physical port” section, where it should probably read:
5 RX Output
and not ‘6’

Good continuation.

Valencia naranja
on 28/09/2021 at 12:50 (https://jensd.be/1183/linux/read-data-from-the-belgian-digital-meter-through-the-p1-port) said:

hello jens,
im trying to work in similar thing on C#, i can understand how u read , but my questions how can i send specific command to the meter ?? for example if i want to read energy for a specific timestamp

jensd
on 28/09/2021 at 14:15 (https://jensd.be/1183/linux/read-data-from-the-belgian-digital-meter-through-the-p1-port) said:

You cannot send any commands to the meter. There is no querying. It simply spits the data out and you can capture it…

Valencia naranja
on 30/09/2021 at 17:08 (https://jensd.be/1183/linux/read-data-from-the-belgian-digital-meter-through-the-p1-port) said:

So the meter send all the data that that is available in the registers ? i mean if want to read energy for specific a time for example (01/10/2021 00H00)

Luc Berger
on 23/12/2023 at 17:03 (https://jensd.be/1183/linux/read-data-from-the-belgian-digital-meter-through-the-p1-port) said:

There is no data stored in the meter: The meter send continuous flow of cur‐

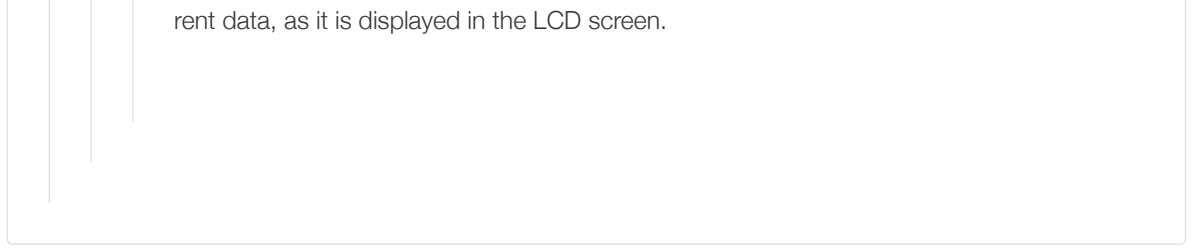
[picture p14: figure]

rent data, as it is displayed in the LCD screen.

Michel
on 24/11/2021 at 20:20 (https://jensd.be/1183/linux/read-data-from-the-belgian-digital-meter-through-the-p1-port) said:

I tried the script, but always get errors about reading the USBport.
I run Python 3.10 installed from python.org on a Windows10 PC.
First I got error that serial.Serial (….) was not known module in serial.
After installing pyserial this problem is solved but now I get errors that port /dev/ttyUSB0 can not be found

Traceback (most recent call last):
File “”, line 1, in
File “D:\Michel\Python\lib\site-packages\serial\serialwin32.py”, line 33, in __init__ super(Serial, self).__init__(*args, **kwargs)
File “D:\Michel\Python\lib\site-packages\serial\serialutil.py”, line 244, in __init__ self.open()
File “D:\Michel\Python\lib\site-packages\serial\serialwin32.py”, line 64, in open
raise SerialException(“could not open port {!r}: {!r}”.format(self.portstr, ctypes.WinError())) serial.serialutil.SerialException: could not open port ‘/dev/ttyUSB0’: FileNotFoundError(2, ‘Het systeem kan het opgegeven pad niet vinden.’, None, 3)

Can someone help with the port configuration (/dev/ttyUSB0) ?

jensd
on 24/11/2021 at 20:22 (https://jensd.be/1183/linux/read-data-from-the-belgian-digital-meter-through-the-p1-port) said:

/dev/ttyUSB0 is how a device looks like under Linux. You will need to replace that with the correct COM-port under Windows (check device manager before and after inserting the USB cable).

Pascal
on 25/07/2022 at 11:07 (https://jensd.be/1183/linux/read-data-from-the-belgian-digital-meter-through-the-p1-port) said:

Bonjour,

La visualisation miniterm est incompréhensible :
python3 -m serial.tools.miniterm /dev/ttyUSB0 115200 –xonxoff
— Miniterm on /dev/ttyUSB0 115200,8,N,1 —
— Quit: Ctrl+] | Menu: Ctrl+T | Help: Ctrl+T followed by Ctrl+H —
??

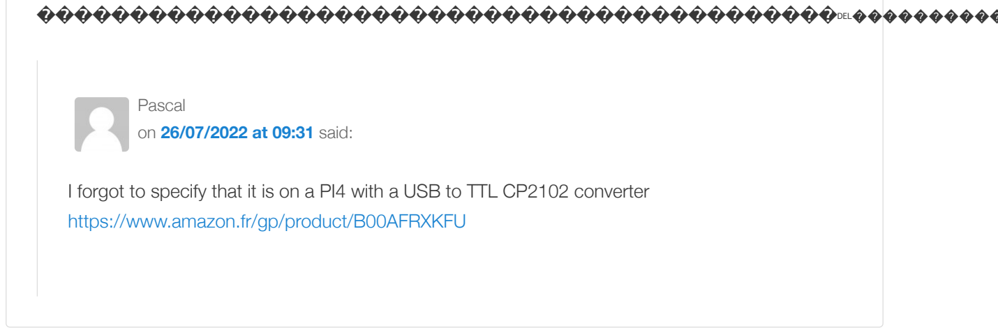
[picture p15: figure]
Pascal on 26/07/2022 at 09:31 said:; https://www.amazon.fr/gp/product/B00AFRXKFU

I forgot to specify that it is on a PI4 with a USB to TTL CP2102 converter

Peter
on 23/09/2022 at 21:03 (https://jensd.be/1183/linux/read-data-from-the-belgian-digital-meter-through-the-p1-port) said:

Can confirm this works on MacOS X. Great work. We’re using this cable: https://webshop.cedel.nl/Slimme-meter-kabel-P1-naar-USB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 (https://webshop.cedel.nl/Slimme-meter-kabel-P1-naar-USB)

petervdv
on 26/11/2022 at 10:55 (https://jensd.be/1183/linux/read-data-from-the-belgian-digital-meter-through-the-p1-port) said:

Thanx jens, got my cable in the mail yesterday, setup a small ubuntu server in the basement,, connected P1 to the server and was up and running in less then an hour thanx to your script. This tineframe includes opening the port on the Fluvius site. This does not include the couple of times I watched your video and read your blog the previous days :-)

Frederik
on 09/01/2023 at 15:27 (https://jensd.be/1183/linux/read-data-from-the-belgian-digital-meter-through-the-p1-port) said:

Nice. I never succeeded in properly ‘syncing’ on the serial stream in (micro)python. This script is really helpful. Thanks for sharing.

jvdvegt
on 14/03/2023 at 22:02 (https://jensd.be/1183/linux/read-data-from-the-belgian-digital-meter-through-the-p1-port) said:

Nice script, thanks! I added CSV export in my fork on GitHub.

Any idea why adding all values for ‘1-0:1.7.0’ (All phases consumption) gives me half of what my energy provider shows? (Same issue with ‘1-0:2.7.0’ (All phases production)).

Bob Harris
on 21/03/2023 at 22:23 (https://jensd.be/1183/linux/read-data-from-the-belgian-digital-meter-through-the-p1-port) said:

Thanks for a very useful piece of work, it’s just what I was looking for.
I am in The Netherlands and have an Iskra MT382 meter from Liander. I am using a P1 cable from BOL.com and running your script on a Rapberry Pi 3A+ with Python 3.7.3 (Thonny).
I set everything up according to your instructions and as far as I can tell the serial data config I need is the same as in your script. I checked that the USB port is indeed /dev/ttyUSB0 (print(ser.name)).
The script does not get beyond “p1line = ser.readline().
When I replace ser.readline() with ser.read(), it returns b’\x00′
With ser.read(10) I get:
“`
Reading: b’\x00′
END
Reading: b”
END
Reading: b”
END
Reading: b”
END
Reading: b’\x00\x00\x00\x00\x00\x00\x00\x00\x00\x00′ END
Reading: b’\x00\x00\x00\x00\x00\x00\x00\x00\x00\x00′ END
Reading: b’\x00\x00\x00\x00\x00\x00\x00\x00\x00\x00′ END
Reading: b’\x00\x00\x00\x00\x00\x00\x00\x00\x00\x00′ END
Reading: b’\x00\x00\x00\x00\x00\x00\x00\x00\x00\x00′ END
Reading: b’\x00\x00\x00\x00\x00\x00\x00\x00\x00\x00′ END
Reading: b’\x00\x00\x00\x00\x00\x00\x00\x00\x00\x00′ END
Reading: b’\x00\x00\x00\x00\x00\x00\x00\x00\x00\x00′ END
“`
where “END” is simply a print statement I put at the end of main()

Presumably I am not seeing the end of line characters and probably not reading the data correctly in the first place. Can you advise what I need to change? Any help would be much appreciated.

Luc Berger
on 23/12/2023 at 17:09 (https://jensd.be/1183/linux/read-data-from-the-belgian-digital-meter-through-the-p1-port) said:

Maybe thonny screw it, try to run the .py in a terminal: python read_p1.py

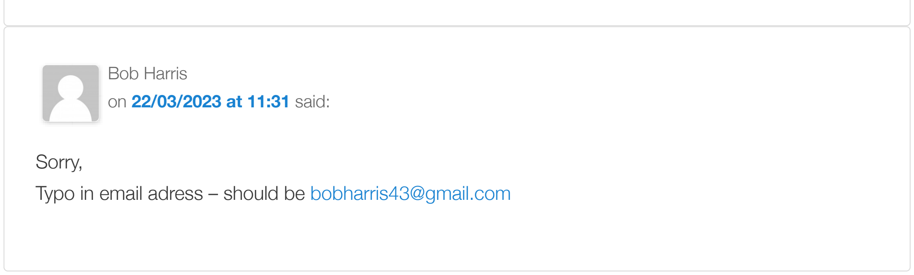
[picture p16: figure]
Bob Harris on 22/03/2023 at 11:31 said:; Sorry,

Typo in email adress – should be bobharris43@gmail.com

Bob Harris
on 22/03/2023 at 12:46 (https://jensd.be/1183/linux/read-data-from-the-belgian-digital-meter-through-the-p1-port) said:

It looks as though my first post has disappeared. I will attempt to repeat it. Sorry if it is a duplicate.

Thanks for your post about the P1 meter, it was just what I was looking for.
I am attempting to read my smartmeter and to integrate the readings with those from other sensors (temp, pressure, humidity) around my home which deliver mqtt messages via node-red to InfluxDB/ Grafana. These are housed on a RPi 4 (4GB) with USB SSD attached. That setup is working well.

For the smartmeter readings I am using a P1 cable (RJ11 to USBA) from BOL.com. I installed your script on a RPi 3A+ and set it up according to your instructions. I am in NL and have an Iskra MT382 meter from my supplier Liander. As far as I can judge from the documentation I need the same serial interface settings as in your article.
I checked (print(ser.name)) that the USB port is /dev/ttyUSB0.

The script seems to hang at the line
> p1line = ser.readline()
If I replace it by by ser.read() I get outputs, but only of the type b’\x00\x00 …..
Presumably the readline command is failing to find the end of line and I assume that I am not actually reading useful values in the first place.

Can you help in any way? (would be much appreciated)

Bob Harris
on 26/03/2023 at 22:01 (https://jensd.be/1183/linux/read-data-from-the-belgian-digital-meter-through-the-p1-port) said:

I managed to read from my P1 port by changing to 9600 baud, 7E1.
I now get the following output (which is very promising), but with error messages concerning: — ValueError
— Port not open.
———-
Reading: b”
Reading: b’/ISk5\\2MT382-1003′
Found beginning of P1 telegram ************************************************************

Reading: b”

Reading: b’0-0:96.1.1(5A424556303035313136303532393132)’ Reading: b’1-0:1.8.1(27115.317*kWh)’
Reading: b’1-0:1.8.2(20508.583*kWh)’
Reading: b’1-0:2.8.1(03395.553*kWh)’
Reading: b’1-0:2.8.2(08095.088*kWh)’ Reading: b’0-0:96.14.0(0001)’ Reading: b’1-0:1.7.0(0000.57*kW)’ Reading: b’1-0:2.7.0(0000.00*kW)’ Reading: b’0-0:17.0.0(0999.00*kW)’ Reading: b’0-0:96.3.10(1)’ Reading: b’0-0:96.13.1()’
Reading: b’0-0:96.13.0()’
Reading: b’0-1:24.1.0(3)’
Reading: b’0-1:96.1.0(3238313031353431313036303036303132)’ Reading: b’0-1:24.3.0(230326210000)(00)(60)(1)(0-1:24.2.1)(m3)’ Reading: b'(24027.445)’
Reading: b’0-1:24.4.0(1)’
Reading: b’!’
Found end, printing full telegram ****************************************
/ISk5\2MT382-1003

0-0:96.1.1(5A424556303035313136303532393132) 1-0:1.8.1(27115.317*kWh)
1-0:1.8.2(20508.583*kWh)
1-0:2.8.1(03395.553*kWh)
1-0:2.8.2(08095.088*kWh)
0-0:96.14.0(0001)
1-0:1.7.0(0000.57*kW)
1-0:2.7.0(0000.00*kW)
0-0:17.0.0(0999.00*kW)
0-0:96.3.10(1)
0-0:96.13.1()
0-0:96.13.0()
0-1:24.1.0(3)
0-1:96.1.0(3238313031353431313036303036303132) 0-1:24.3.0(230326210000)(00)(60)(1)(0-1:24.2.1)(m3) (24027.445)
0-1:24.4.0(1)
!
****************************************
Traceback (most recent call last):
File “/home/pi/Smartmeter/jdepuyt_script.py”, line 137, in main
if checkcrc(p1telegram):
File “/home/pi/Smartmeter/jdepuyt_script.py”, line 58, in checkcrc givencrc = hex(int(p1telegram[match.end() + 1:].decode(‘ascii’).strip(), 16)) ValueError: invalid literal for int() with base 16: ”

Something went wrong…
Traceback (most recent call last):
File “/home/pi/Smartmeter/jdepuyt_script.py”, line 163, in

main()
File “/home/pi/Smartmeter/jdepuyt_script.py”, line 160, in main ser.flush()
File “/usr/lib/python3/dist-packages/serial/serialposix.py”, line 588, in flush raise portNotOpenError
serial.serialutil.SerialException: Attempting to use a port that is not open ——–
Can anybody help me please?

Cédric Vanzuyt
on 13/04/2023 at 21:28 (https://jensd.be/1183/linux/read-data-from-the-belgian-digital-meter-through-the-p1-port) said:

Great topic. Thank you for this.
Unfortunately, I’m a newbee….
I would like to import the data in Home Assistant.
Do you think it would be possible to create an integration with Home Assistant ? On the home assistant Computer, there is a usb cable connected to P1 port.

Thank you

Jan de Chaffoy - ON1DU
on 15/04/2023 at 01:13 (https://jensd.be/1183/linux/read-data-from-the-belgian-digital-meter-through-the-p1-port) said:

Hi Jens,
my setup:

Libre computer Le Potato (since Raspberry Pi has become way too expensive) from Ali: https://nl.aliexpress.com/item/1005005163398168.html
USB cable from Ali: https://nl.aliexpress.com/item/1005001747429524.html
Power Supply from Ali: https://nl.aliexpress.com/item/1005001808187610.html
Case from Ali: https://nl.aliexpress.com/item/1005004321021256.html
Power Supply wire from Ali: https://nl.aliexpress.com/item/1005004993007922.html
SD card from Ali (64 Gb): https://nl.aliexpress.com/item/1005004495732671.html

Setup worked from the first time. All I had to do was to cut the +5V wire in the USB cable. Cheers

Bernard Lheureux
on 11/08/2023 at 11:59 (https://jensd.be/1183/linux/read-data-from-the-belgian-digital-meter-through-the-p1-port) said:

Thanks a lot, work perfectly. Can you tell me where I can put a time.sleep(10) to slowdown the scrip ? Thanks in advance.

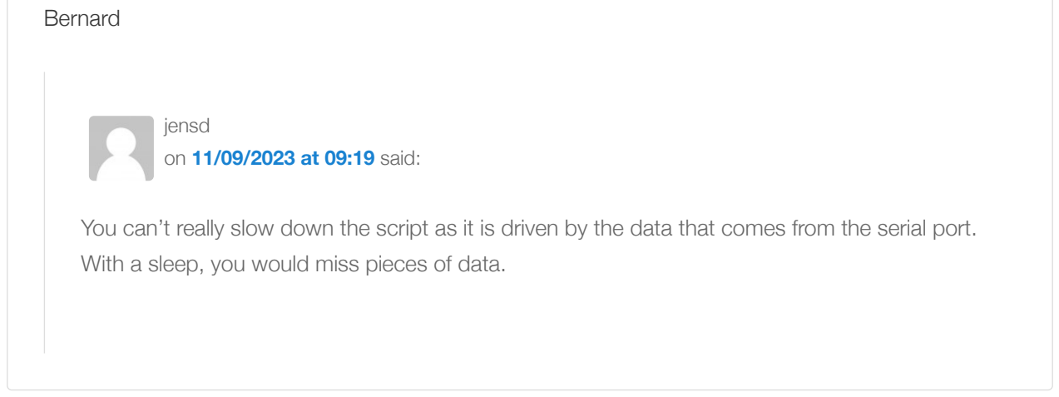
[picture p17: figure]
Bernard; jensd on 11/09/2023 at 09:19 said:

You can’t really slow down the script as it is driven by the data that comes from the serial port. With a sleep, you would miss pieces of data.

Thomas Blomme
on 10/09/2023 at 14:31 (https://jensd.be/1183/linux/read-data-from-the-belgian-digital-meter-through-the-p1-port) said:

Hi Jens, many thanks for your script. I’ve copied it and added an InfluxDB logger so I can visualise it in Grafana.

Mebrotus
on 25/09/2023 at 16:46 (https://jensd.be/1183/linux/read-data-from-the-belgian-digital-meter-through-the-p1-port) said:

Hi Jens, nice article ! tx.

My current setup:
– easymeter 59€
https://easynrj.com/nl/products/easymeter-digitalmeter-informatie-p1?variant=44760509907248 and with this one I also see my capacity tariff info (monthly & 12-months peaks). Very usefull in Flanders with the new capaciteitstarief.

All info go directly to my homeassistant

Meb

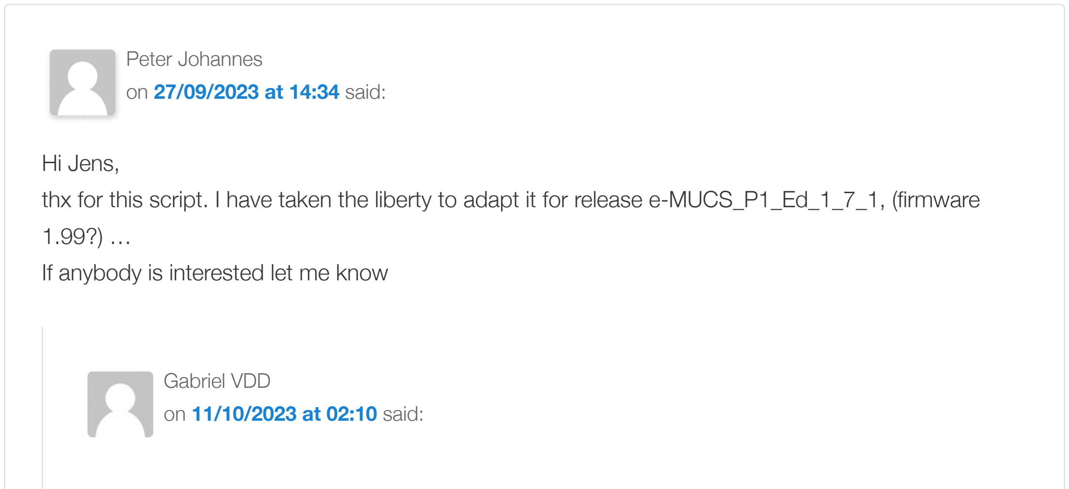
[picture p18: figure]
Peter Johannes on 27/09/2023 at 14:34 said:; Hi Jens,; 1.99?) … If anybody is interested let me know; Gabriel VDD on 11/10/2023 at 02:10 said:

thx for this script. I have taken the liberty to adapt it for release e-MUCS_P1_Ed_1_7_1, (firmware

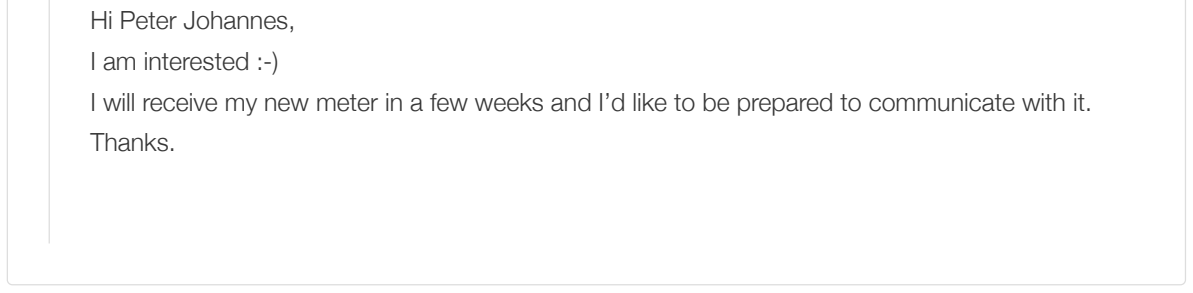
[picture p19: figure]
Hi Peter Johannes, I am interested :-); Thanks.

I will receive my new meter in a few weeks and I’d like to be prepared to communicate with it.

Thomas89
on 18/10/2023 at 12:58 (https://jensd.be/1183/linux/read-data-from-the-belgian-digital-meter-through-the-p1-port) said:

Hi Jens and thanks a lot for what you’ve done here.

I am looking for a way to activate the P1 port for free. Yes, unfortunately Ores charges around 27€ for this and you’ve got to wait for the technician to come.

Any chance you could help me on that?

Cheers,
Thomas

Ruben
on 31/01/2024 at 20:39 (https://jensd.be/1183/linux/read-data-from-the-belgian-digital-meter-through-the-p1-port) said:

Hi Jens,

Thank you very much for sharing.
I just tested this in my raspberry 4B on ubuntu 22.04LTS, connected to Fluvius digital meter, and works perfectly well from the first run. Awesome !

Thanks !

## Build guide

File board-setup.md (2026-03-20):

# Board setup — Heltec CubeCell HTCC-AB02A

This guide covers driver installation, Arduino IDE board support, and how to flash a sketch.

Official product page: [heltec.org/project/htcc-ab02a](https://heltec.org/project/htcc-ab02a/)
Official documentation: [docs.heltec.org — CubeCell HTCC-AB02A](https://docs.heltec.org/en/node/asr650x/htcc-ab02a/index.html)

---

## 1 — Install the USB driver

The HTCC-AB02A uses a **CP2102** USB-to-UART bridge (Silicon Labs).

| OS | Action |
|----|---|
| Windows 10/11 | Usually installed automatically via Windows Update. If the port does not appear in Device Manager, download the driver from [silabs.com/developers/usb-to-uart-bridge-vcp-drivers](https://www.silabs.com/developers/usb-to-uart-bridge-vcp-drivers) and run the installer. |
| macOS | Download and install the CP210x driver from the same Silicon Labs page above. Reboot after installation. |
| Linux | The `cp210x` kernel module is included in most distributions. Plug in the board — a `/dev/ttyUSB0` (or similar) device should appear immediately. |

After installation, connect the board via USB. A serial port should appear:
- Windows: `COMx` in Device Manager → Ports (COM & LPT)
- macOS: `/dev/cu.SLAB_USBtoUART` or `/dev/cu.usbserial-*`
- Linux: `/dev/ttyUSB0`

---

## 2 — Install Arduino IDE

Download Arduino IDE 2.x from [arduino.cc/en/software](https://www.arduino.cc/en/software).

---

## 3 — Add Heltec CubeCell board support

1. Open **File → Preferences** (macOS: **Arduino IDE → Settings**).
2. In the **Additional boards manager URLs** field, add:
   ```
   https://resource.heltec.cn/download/package_CubeCell_index.json
   ```
3. Click **OK**.
4. Open **Tools → Board → Boards Manager**.
5. Search for `CubeCell` and install **Heltec CubeCell Series (ASR650x)**.

---

## 4 — Configure the board

Go to **Tools** and set:

| Setting | Value |
|---|---|
| Board | `CubeCell-Board (HTCC-AB02A)` |
| LORAWAN_REGION | `REGION_EU868` (Belgium) |
| LORAWAN_CLASS | `CLASS_A` |
| LORAWAN_NETMODE | `OTAA` |
| LORAWAN_ADR | `ON` |
| LORAWAN_UPLINKMODE | `UNCONFIRMED` |
| LORAWAN_Net_Reserve | `OFF` |
| LORAWAN_AT_SUPPORT | `OFF` |
| LORAWAN_DEVEUI | `CUSTOM` |
| Port | select the CP2102 serial port |

---

## 5 — Generate credentials

Use the [`credentials.py`](credentials.py) script to generate OTAA credentials and deploy them. Requires Python 3.7+.

### Option A — write into credentials.h (recommended)

This embeds the keys directly in the firmware at compile time.

```bash
# Generate random credentials and write to a sketch folder
python credentials.py --write-h mono-phase-lorawan/credentials.h

# Write the same credentials to all sketch folders at once
python credentials.py \
  --write-h mono-phase-lorawan/credentials.h \
  --write-h three-phase-lorawan/credentials.h \
  --write-h mono-phase-overvoltage/credentials.h

# Use your own keys (colons optional)
python credentials.py \
  --deveui A8:17:58:FF:FE:0C:A6:4F \
  --appeui 0000000000000000 \
  --appkey AABBCCDDEEFF00112233445566778899 \
  --write-h mono-phase-lorawan/credentials.h
```

The script prints the credentials (colon format for the network server) and the C array declarations, then writes `credentials.h`. Register the DevEUI / AppEUI / AppKey on your LoRaWAN network server (TTN, Chirpstack, etc.) before flashing.

### Option B — send via AT commands

If the firmware is already flashed and was compiled with **LORAWAN_AT_SUPPORT ON**, credentials can be pushed over serial without reflashing. Requires pyserial:

```bash
pip install pyserial
```

```bash
# macOS / Linux
python credentials.py --at-send /dev/cu.usbserial-0001

# Windows
python credentials.py --at-send COM3
```

The script sends `AT+LPM=0`, `AT+DevEui=`, `AT+AppEui=`, `AT+AppKey=` in sequence and prints each response.

---

## 6 — Flash a sketch

> **WARNING — do not connect both power sources at the same time.**
> The board can be powered from the meter's 5 V line (VIN) or from USB — never both simultaneously.
> Disconnect the P1 RJ11 cable before connecting USB for programming, then reconnect it afterwards.

1. Generate `credentials.h` with `credentials.py` (see section 5).
2. Open the sketch folder (e.g. `mono-phase-lorawan/`) in Arduino IDE.
3. Click **Upload** (→ arrow button) or press `Ctrl+U` / `Cmd+U`.
4. The IDE compiles and flashes. The board resets automatically when done.
5. Open **Tools → Serial Monitor** at **115200 baud** to see debug output (only while USB is connected).

---

## Troubleshooting

**Port not found / upload fails**
- Check the USB cable supports data (some cables are power-only).
- Reinstall the CP2102 driver and reboot.
- On macOS, check **System Settings → Privacy & Security** — the Silicon Labs kernel extension may need explicit approval.

**Board resets during upload**
- This is normal — the bootloader resets the chip to enter flash mode.

**LoRaWAN join fails**
- Double-check DevEUI, AppEUI, and AppKey in `credentials.h`.
- Confirm your LoRaWAN network server has the device registered with matching keys.
- Make sure you are within range of a gateway on EU868.

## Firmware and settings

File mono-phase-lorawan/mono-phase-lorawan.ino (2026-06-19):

#include <LoRaWan_APP.h>
#include "elec_reader.h"
#include "elec_stats.h"
#include "elec_timestamp.h"
#include "dht_reader.h"
#include "credentials.h"

#define INVERTER_POWER_GPIO_PIN GPIO10
#define ELECTRICAL_METER_DATAREQUEST_GPIO_PIN GPIO7
#define UNUSED_GPIO_PIN GPIO5  // used to generate random seed
#define DHT_GPIO_PIN GPIO9     // DHT22 data pin

#define USER_BUTTON_GPIO_PIN USER_KEY  // The interrupt pin is attached to USER_SW


#define LED_INDICATOR_GPIO_PIN GPIO1

#define TIMEOUT 10          //time in ms
#define DEBOUNCE_DELAY 360  // Debounce delay in milliseconds

#define LORA_ELEC_FRAME_VERSION 2  // Bumped to v2 for DHT22 support
#define ELEC_METER_NB_PHASES 1
#define APPPORT 1  // LoRaWAN app port
#define LORA_RANDOM_DELAY_TRANSMIT_S_MIN 15 // delay between new quarter and effective transmission.
#define LORA_RANDOM_DELAY_TRANSMIT_S_MAX 60 // delay between new quarter and effective transmission.

#define ENABLE_LORAWAN 1

#define DEBUG 0  //all debug controlled here, set DEBUG 0 to DEBUG 1 to turn on debug, set DEBUG 1 to DEBUG 0 to turn off debug

#if DEBUG
#define debug(...) Serial.print(__VA_ARGS__)
#define debugln(...) Serial.println(__VA_ARGS__)
#define debugdelay(x) delay(x)
#else
#define debug(...)
#define debugln(...)
#define debugdelay(x)
#endif


/* LoRaWAN credentials are in credentials.h (not committed to git) */

/*LoraWan channelsmask, default channels 0-7*/
uint16_t userChannelsMask[6] = { 0x00FF, 0x0000, 0x0000, 0x0000, 0x0000, 0x0000 };

/*LoraWan region, select in arduino IDE tools*/
LoRaMacRegion_t loraWanRegion = LORAMAC_REGION_EU868;

/*LoraWan Class, Class A and Class C are supported*/
DeviceClass_t loraWanClass = CLASS_A;
/*OTAA or ABP*/
bool overTheAirActivation = true;

/*ADR enable*/
bool loraWanAdr = LORAWAN_ADR;

/* set LORAWAN_Net_Reserve ON, the node could save the network info to flash, when node reset not need to join again */
bool keepNet = LORAWAN_NET_RESERVE;

/* Indicates if the node is sending confirmed or unconfirmed messages */
bool isTxConfirmed = LORAWAN_UPLINKMODE;

/* Application port */
uint8_t appPort = APPPORT;

/*the application data transmission duty cycle.  value in [ms].*/
uint8_t txInterval = 6;                          // 1h;
uint32_t appTxDutyCycle = (1 * 60 * 60 * 1000);  // not used but requeried byt arduino lib

/*!
* Number of trials to transmit the frame, if the LoRaMAC layer did not
* receive an acknowledgment. The MAC performs a datarate adaptation,
* according to the LoRaWAN Specification V1.0.2, chapter 18.4, according
* to the following table:
*
* Transmission nb | Data Rate
* ----------------|-----------
* 1 (first)       | DR
* 2               | DR
* 3               | max(DR-1,0)
* 4               | max(DR-1,0)
* 5               | max(DR-2,0)
* 6               | max(DR-2,0)
* 7               | max(DR-3,0)
* 8               | max(DR-3,0)
*
* Note, that if NbTrials is set to 1 or 2, the MAC will not decrease
* the datarate, in case the LoRaMAC layer did not receive an acknowledgment
*/
uint8_t confirmedNbTrials = 4;

int app_fail;  // used by tele converter to count the number of failed read from the meter.
uint8_t last_quarter_transmitted = 0;
uint32_t next_transmission_timestamp = 0;
bool transmission_needed = false;
bool first_msg_received = true;


volatile bool userButtonInterrupt = false;
volatile uint32_t lastUserButtonInterrupt = 0;

void onUserButton() {
  // Debounce the interrupt
  if ((lastUserButtonInterrupt + DEBOUNCE_DELAY) > millis()) {
    return;
  }
  lastUserButtonInterrupt = millis();

  userButtonInterrupt = true;
}

void setup() {

  // init random
  randomSeed(analogRead(UNUSED_GPIO_PIN));

  // Initialize Serial1 (USB serial) at a baud rate of 115200
  Serial.begin(115200);

  Serial.println("Serial 1 is setup.");

  //Set power ON for the inverter : 3.3V
  pinMode(INVERTER_POWER_GPIO_PIN, OUTPUT);
  digitalWrite(INVERTER_POWER_GPIO_PIN, HIGH);

  /**
    The A1 port is activated (start sending data) by setting 'Data Request' line high (to +5V).
    While receiving data, the requesting OSM must keep the 'Data Request' line activated (set to +5V).
    To stop receiving data the OSM has to drop the 'Data Request' line (set it to 'high impedance' mode); hence,
    the data transfer will stop immediately.
    For backward compatibility reasons, no OSM is allowed to set the 'Data Request' line low (set it to GND or 0V).

    For these reason we are using   OD_HI : Open Drain, Drives High
    3.3V when set high
    Open collector (not GND) when set down.
  **/
  pinMode(ELECTRICAL_METER_DATAREQUEST_GPIO_PIN, OD_HI);
  digitalWrite(ELECTRICAL_METER_DATAREQUEST_GPIO_PIN, LOW);

  /*
    Initialize second Serial (hardware serial) at a baud rate of 115200 (or the baud rate required by your electrical meter)
    Port settings for P1 are 115200 baud, 8N1, Xon/Xoff.
    Serial1.begin(uint32_t baud=115200, uint32_t config=SERIAL_8N1, int rxPin=-1, int txPin=-1, bool invert=false, unsigned long timeout_ms = 1000UL)
  */
  Serial1.begin(115200, SERIAL_8N1, UART_RX2, UART_TX2, false, 1000UL);

  Serial.println("Serial 2 is setup.");

  /* Enable VEXT to power the DHT22 sensor (mains-powered device, always on) */
  pinMode(Vext, OUTPUT);
  digitalWrite(Vext, LOW);  // LOW = VEXT ON on CubeCell

  /* Initialize DHT22 sensor */
  dht_init(DHT_GPIO_PIN);
  delay(2000);  // DHT22 requires 2s warm-up before first valid read
  dht_read();
  Serial.printf("DHT22 initial read: %.1f°C, %.1f%%\n", dht_get_temperature(), dht_get_humidity());

  /* Initialize the elec reader */
  elec_init();
  reset_elec_stats();

  //request data from the elec meter
  digitalWrite(ELECTRICAL_METER_DATAREQUEST_GPIO_PIN, HIGH);

  Serial.printf("\n");
  app_fail = 0;


#if (AT_SUPPORT)
  Serial.println("Enable AT support");
  enableAt();
#endif

#if (ENABLE_LORAWAN == 1)

#if (LORAWAN_DEVEUI_AUTO)
  LoRaWAN.generateDeveuiByChipID();
#endif
#if (AT_SUPPORT)
  Serial.println("AT enable getDevParam");
  getDevParam();
#endif
  printDevParam();
  LoRaWAN.init(loraWanClass, loraWanRegion);
  LoRaWAN.ifskipjoin();
  delay(5);
  deviceState = DEVICE_STATE_JOIN;
#else

  deviceState = DEVICE_STATE_CYCLE;
#endif /*ENABLE_LORAWAN */

  //setup user button
  pinMode(USER_BUTTON_GPIO_PIN, INPUT_PULLDOWN);
  attachInterrupt(USER_BUTTON_GPIO_PIN, onUserButton, RISING);

  // setup indicator LED
  pinMode(LED_INDICATOR_GPIO_PIN, OUTPUT);
  digitalWrite(LED_INDICATOR_GPIO_PIN, HIGH);
}

uint8_t add_uint_32_to_app_data(uint32_t value, uint8_t index) {
  appData[index] = value & 0xFF;              // LSB
  appData[index + 1] = (value >> 8) & 0xFF;   // Middle byte
  appData[index + 2] = (value >> 16) & 0xFF;  // More significant byte
  appData[index + 3] = (value >> 24) & 0xFF;  // Most significant byte
  return index + 4;
}


uint8_t add_uint_24_to_app_data(uint32_t value, uint8_t index) {
  /*
   * Used to store Min, Max, mean value into paylaod.
   * We do not need to send the Most Signifiant byte is value is always 0.
   * Max value is 99999.
  */
  appData[index] = value & 0xFF;              // LSB
  appData[index + 1] = (value >> 8) & 0xFF;   // Middle bytes
  appData[index + 2] = (value >> 16) & 0xFF;  // More significant bytes
  return index + 3;
}

uint8_t add_uint_16_to_app_data(uint16_t value, uint8_t index) {
  appData[index] = value & 0xFF;             // LSB
  appData[index + 1] = (value >> 8) & 0xFF;  // Middle byte
  return index + 2;
}


uint8_t add_stats_values_to_app_data(uint8_t stats_index, uint8_t app_data_index) {
  /*
   * Add Min, Max, Mean values to the paylaod (app_data).
  */
  add_uint_24_to_app_data(get_elec_stat_min_value(stats_index), app_data_index);
  add_uint_24_to_app_data(get_elec_stat_max_value(stats_index), app_data_index + 3);
  add_uint_24_to_app_data(get_elec_stat_mean_value(stats_index), app_data_index + 6);
  return app_data_index + 9;
}

uint8_t add_dht22_to_app_data(uint8_t index) {
  /*
   * Add DHT22 readings to payload (2 bytes).
   * Temperature: (value / 2) - 40 = °C
   * Humidity: 0-100%
   */
  dht_read();
  appData[index] = dht_get_encoded_temperature();
  appData[index + 1] = dht_get_encoded_humidity();
  return index + 2;
}

void prepareLoraFrame(bool user_btn_pressed) {
  /*
     * App port is 1
     * Frame format (v2):
      +-------------------+-------------+-------+---------------------------+
      | Value             | Size (bits) | Index | Detail                    |
      +-------------------+-------------+-------+---------------------------+
      | Frame_version     | 4           | 0     | value: 2                  |
      | USR Button        | 1           | 0     | Pressed == 1              |
      | NB Phases         | 2           | 0     | value: 1                  |
      | RESERVED          | 1           | 0     | false                     |
      | Timestamp         | 32          | 1     | Unix timestamp            |
      | Cons-Day-Wh       | 32          | 5     | Current value             |
      | Cons-Night-Wh     | 32          | 9     | Current value             |
      | Prod-Day-Wh       | 32          | 13    | Current value             |
      | Prod-Night-Wh     | 32          | 17    | Current value             |
      | Night1-Day2       | 8           | 21    | Current tariff            |
      | Nb Samples        | 16          | 22    | Sample count              |
      | Cons-W-stats      | 72          | 24    | Min/Max/Mean              |
      | Prod-W-stats      | 72          | 33    | Min/Max/Mean              |
      | L1-dV-stats       | 72          | 42    | Min/Max/Mean (decivolts)  |
      | L1-cA-stats       | 72          | 51    | Min/Max/Mean (centiamps)  |
      | Temperature       | 8           | 60    | (val/2)-40 = °C           |
      | Humidity          | 8           | 61    | 0-100%                    |
      +-------------------+-------------+-------+---------------------------+
      Frame size: 62 bytes
     */
  uint8_t index = 0;

  digitalWrite(LED_INDICATOR_GPIO_PIN, LOW);
  appData[index] = (LORA_ELEC_FRAME_VERSION & 0XF) << 4 | (user_btn_pressed ? 1 : 0) << 3 | (ELEC_METER_NB_PHASES & 0x3) << 1;
  index++;
  index = add_uint_32_to_app_data(getElecTimstamp(), index);
  index = add_uint_32_to_app_data(elec_field_int_value(CONS_DAY_WH_INDEX), index);
  index = add_uint_32_to_app_data(elec_field_int_value(CONS_NIGHT_WH_INDEX), index);
  index = add_uint_32_to_app_data(elec_field_int_value(PROD_DAY_WH_INDEX), index);
  index = add_uint_32_to_app_data(elec_field_int_value(PROD_NIGHT_WH_INDEX), index);
  appData[index] = elec_field_int_value(NIGHT1_DAY2_FLAG_INDEX);
  index++;
  index = add_uint_16_to_app_data(get_elec_stat_nb_samples(CONS_W_STATS_INDEX), index);
  index = add_stats_values_to_app_data(CONS_W_STATS_INDEX, index);
  index = add_stats_values_to_app_data(PROD_W_STATS_INDEX, index);
  index = add_stats_values_to_app_data(INST_L1_DECI_V_STATS_INDEX, index);
  index = add_stats_values_to_app_data(INST_L1_CENTI_A_STATS_INDEX, index);

  // DHT22 temperature and humidity (2 bytes)
  index = add_dht22_to_app_data(index);

  appDataSize = index;
  if (appDataSize > sizeof(appData)) {
    Serial.println("Error: appData size exceeds buffer");
    return;
  }

  digitalWrite(LED_INDICATOR_GPIO_PIN, HIGH);
}


void process_elec_message() {
  uint32_t elect_timestamp = getElecTimstamp();
  uint8_t current_msg_quarter = getQuarterFromTimestamp(elect_timestamp);
  Serial.printf("current_msg_quarter %d %-15s\n", current_msg_quarter, elec_field_value(TIMESTAMP_INDEX));
  for (int i = 0; i < TELE_NUMFIELDS; i++) {
    // update stat
    if (elec_field_has_stat(i)) {
      update_elec_stats(elec_field_stat_index(i), elec_field_int_value(i));
      debug("i %-15s %d\n", elec_field_name(i), get_elec_stat_max_value(elec_field_stat_index(i)));
    } else {
      debug("elec_field_has no stat %d \n", i);
    }
  }

  if (first_msg_received) {
    debug("first_msg_received\n");
    last_quarter_transmitted = current_msg_quarter;
    first_msg_received = false;
  }
  if (current_msg_quarter != last_quarter_transmitted) {
    /*
      New quarter detected, prepare new frame and set flag to transmit it after random delay.
    */
    debug("Prepare new frame\n");
    prepareLoraFrame(false);
    transmission_needed = true;
    next_transmission_timestamp = elect_timestamp + random(LORA_RANDOM_DELAY_TRANSMIT_S_MIN, LORA_RANDOM_DELAY_TRANSMIT_S_MAX);
    last_quarter_transmitted = current_msg_quarter;

    debug("reset_elect_stats\n");
    reset_elec_stats();
  }
  if (transmission_needed) {
    debug("transmission_needed %l\n", next_transmission_timestamp);
    if (next_transmission_timestamp <= elect_timestamp) {
      sendPulseFrame();
      transmission_needed = false;
    }
  }
}
void sendPulseFrame() {
  digitalWrite(LED_INDICATOR_GPIO_PIN, LOW);

  //request data from the elec meter
  digitalWrite(ELECTRICAL_METER_DATAREQUEST_GPIO_PIN, LOW);
  LoRaWAN.send();  // Send the pulse count payload

  Serial.println("Sent msg.");

  //request data from the elec meter
  digitalWrite(ELECTRICAL_METER_DATAREQUEST_GPIO_PIN, HIGH);

  digitalWrite(LED_INDICATOR_GPIO_PIN, HIGH);
}

void loop() {
  if (userButtonInterrupt) {
    userButtonInterrupt = false;
    Serial.println("USR btn pressed");
    prepareLoraFrame(true);
    sendPulseFrame();
  }

  switch (deviceState) {
    case DEVICE_STATE_JOIN:
      {
        LoRaWAN.join();
        break;
      }
    case DEVICE_STATE_CYCLE:
      {
        // Only read if data is available, otherwise pass -1 for timeout handling
        int ch = Serial1.available() ? Serial1.read() : -1;
        Tele_Result res = elec_parser_add(ch);

        if (res == TELE_RESULT_ERROR) app_fail++;
        if (res == TELE_RESULT_AVAILABLE) {
          debug("elec values: available\n  %-15s %d\n", "Num-Fail", app_fail);
          debugdelay(200);  //allow lora mac to run.

          for (int i = 0; i < TELE_NUMFIELDS; i++) {
            debug("  %-15s %s\n", elec_field_name(i), elec_field_value(i));
            debugdelay(200);  //allow lora mac to run.
          }
          process_elec_message();

          Serial.printf("End processing \n");
          delay(200);
          app_fail = 0;
        }
        break;
      }
    default:
      {
        deviceState = DEVICE_STATE_CYCLE;
        break;
      }
  }
}

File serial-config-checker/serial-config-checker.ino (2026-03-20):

#define INVERTER_POWER_GPIO_PIN GPIO10
#define ELECTRICAL_METER_DATAREQUEST_GPIO_PIN GPIO7
#define TIMEOUT 10//time in ms

#define SERIAL_BUFFER_SIZE (1024+2)
uint8_t serialBuffer[SERIAL_BUFFER_SIZE];
int size;

void setup() {
  // Initialize Serial1 (USB serial) at a baud rate of 115200
  Serial.begin(115200);

  Serial.println("Serial 1 setup.");

  Serial.println("Serial 2 setup.");
  //Alimentation for the inverter : 3.3V
  pinMode(INVERTER_POWER_GPIO_PIN, OUTPUT);
  digitalWrite(INVERTER_POWER_GPIO_PIN, HIGH);

  /**
    The A1 port is activated (start sending data) by setting 'Data Request' line high (to +5V).
    While receiving data, the requesting OSM must keep the 'Data Request' line activated (set to +5V).
    To stop receiving data the OSM has to drop the 'Data Request' line (set it to 'high impedance' mode); hence,
    the data transfer will stop immediately.
    For backward compatibility reasons, no OSM is allowed to set the 'Data Request' line low (set it to GND or 0V).

    For these reason we are using   OD_HI : Open Drain, Drives High
    3.3V when set high
    Open collector (not GND) when set down.
  **/
  pinMode(ELECTRICAL_METER_DATAREQUEST_GPIO_PIN, OD_HI);
  digitalWrite(ELECTRICAL_METER_DATAREQUEST_GPIO_PIN, LOW);

  /*
    Initialize second Serial (hardware serial) at a baud rate of 115200 (or the baud rate required by your electrical meter)
    Port settings for P1 are 115200 baud, 8N1, Xon/Xoff.
    Serial1.begin(uint32_t baud=115200, uint32_t config=SERIAL_8N1, int rxPin=-1, int txPin=-1, bool invert=false, unsigned long timeout_ms = 20000UL)
  */
  Serial1.begin(115200, SERIAL_8N1, UART_RX2, UART_TX2, false, 20000UL);

  Serial.println("Serial 2 setup.");
}



uint16_t readSerial1Until(char terminator, char *buffer, uint16_t buffer_length){
  /*
  Read Serial1 until the terminator character and up to buffer_lenght characters
  return the number of characters readed.
  */
  uint16_t nb_char_readed = 0;

  // Read characters while there is data available and buffer is not full
  while (nb_char_readed < buffer_length - 1 && Serial1.available()) {
    char c = Serial1.read();  // Read a character from Serial1

    // Check if the character matches the terminator
    if (c == terminator) {
      break;  // Stop reading if the terminator is found
    }

    // Store the character in the buffer
    buffer[nb_char_readed++] = c;

    //Wait up to 1 ms for the next character
    int i = 0;
    while(i<1000)
    {
        if(Serial1.available())
            break;
        delayMicroseconds(1);
        i++;
    }
  }

  // Add null terminator to make the buffer a valid C-string
  buffer[nb_char_readed] = '\0';

  // Return the number of characters read
  return nb_char_readed;
}




bool readOneMeterMessage() {
  /**
    Read a message up to the end.
    Each line end up with '\n'.
    The longest line is in code 0-0:96.13.0.255, up to 1024 character so serialBuffer need to be 1026 characters.
  */

  //request data from the meter
  digitalWrite(ELECTRICAL_METER_DATAREQUEST_GPIO_PIN, HIGH);
  bool message_ended = false;
  uint16_t len = 0;

  if (Serial.available()) {
    // meter start sending data, stop the request (we only want one message)
    digitalWrite(ELECTRICAL_METER_DATAREQUEST_GPIO_PIN, LOW);
    while(!message_ended){

      memset(serialBuffer, 0, sizeof(serialBuffer));
      len = readSerial1Until('\n', (char*)serialBuffer, SERIAL_BUFFER_SIZE);
      if (len < SERIAL_BUFFER_SIZE){
        serialBuffer[len] = '\n';
        serialBuffer[len + 1] = 0;
      }

    }
  }
}


void loop() {
  // Check if there is data available on Serial2
  if (Serial1.available()) {
    // Read data from Serial2
    char incomingByte = Serial1.read();

    // Write the data to Serial1
    Serial.write(incomingByte);
  }

  // size = Serial.read(serialBuffer,TIMEOUT);
  // if(size)
  // {
  //   Serial.printf("rev data size %d : ",size);
  //   Serial.write(serialBuffer,size);
  //   // Serial.write("\r\n");
  // }
}

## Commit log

2026-03-20 Fix type mismatch in readSerial1Until call
    Remove & from serialBuffer and cast to char* to match the function
    signature expecting char* instead of uint8_t(*)[1026].
    [serial-config-checker.ino]
2026-03-20 Remove static from credentials variable declarations
    LoRaWan_APP.h declares devEui, appEui, appKey, nwkSKey, appSKey and
    devAddr as extern, so redeclaring them static causes a -fpermissive
    error. Remove static from the template and all generated .h.example
    files.
    [credentials.py]
2026-03-20 Fix undefined TELE_VALUE_SIZE in elec_field_int_value
    Rename to OBIS_VALUE_SIZE which is the actual constant defined in
    elec_reader.h.
    [elec_reader.cpp]
2026-03-27 Chore document Arduino library dependencies in README
    Add DHT sensor library installation step (Adafruit DHT + Adafruit
    Unified Sensor) to the quick start guide.
2026-04-13 Add CLAUDE.md and document Arduino library dependencies in README
    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
2026-04-13 feat: add PCB
    [electrical-input-inverter-3-3v_v2.fzz, p1-meter-lorawan-v2.fzz]
2026-06-19 fix: DHT22 sensor setup and GPIO port
    [dht_reader.cpp, mono-phase-lorawan.ino, mono-phase-overvoltage.ino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]
2026-06-19 feat: add PCB v2.1 (working board)
    [electrical-input-inverter-3-3v_v2.1.fzz, p1-meter-lorawan-v2.1.fzz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]
2026-06-21 Chore: add pictures of the PCB
